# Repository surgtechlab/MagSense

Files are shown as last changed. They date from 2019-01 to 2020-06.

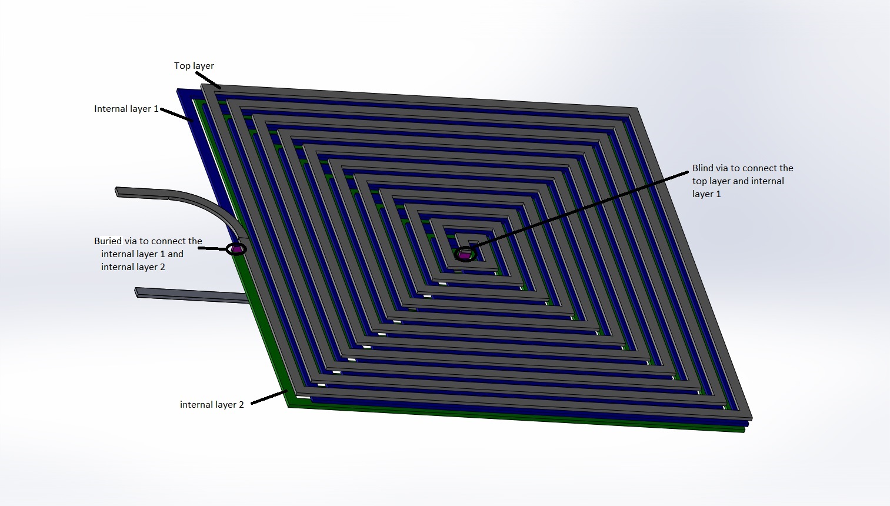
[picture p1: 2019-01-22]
02_Design/unityBoards/fromLefan/One_FS coil_Front view.JPG

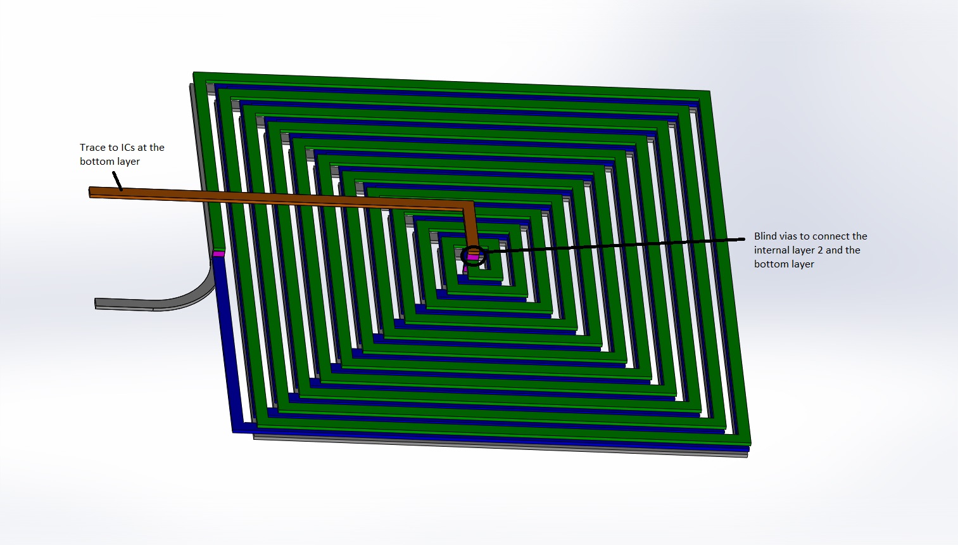
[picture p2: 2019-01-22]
02_Design/unityBoards/fromLefan/One_FScoil_Back view.JPG

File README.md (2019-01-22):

# MagSense

Code and Library for the Leeds Surgical Technologies Lab - Magnetic Sensing Platform

Maintained by Pete Culmer

Contributions from:
******************************
Chris Adams
Max Houghton
Pete Culmer
Belquis Haider

Links:
******************************
This owes a debt to the more general purpose MLX90393 driver
https://github.com/tedyapo/arduino-MLX90393

TODO LIST
******************************
Add Bluetooth communication
 
Simplify I2C code
  ***Use wrapper function to provide a single interface to the mutliple I2C buses - for the commands below:
  Wire.beginTransmission(_I2CAddress);
  Wire.write(0x80)
  Wire.endTransmission()
  Wire.requestFrom(_I2CAddress, 1);
  Wire.available()
  Wire.read();

Add handshaking and commands to I2C comms
  Start/stop/reset/ack packet etc.
  
Improve error checking of chip configuration (check registers after config)

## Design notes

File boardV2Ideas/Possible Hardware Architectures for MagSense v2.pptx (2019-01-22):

## Possible Hardware Architectures for MagSense v2

## Device

- Two interface protocols
  - i2c transfer up to 400 kHz
    - Not achieving this currently, possible clock stretching?
  - SPI transfer up to 10 MHz
  - Protocols very similar but SPI untested
- Running in burst mode
  - Should return last measurement obtained when read
  - Has interrupt pin to indicate measurement ready

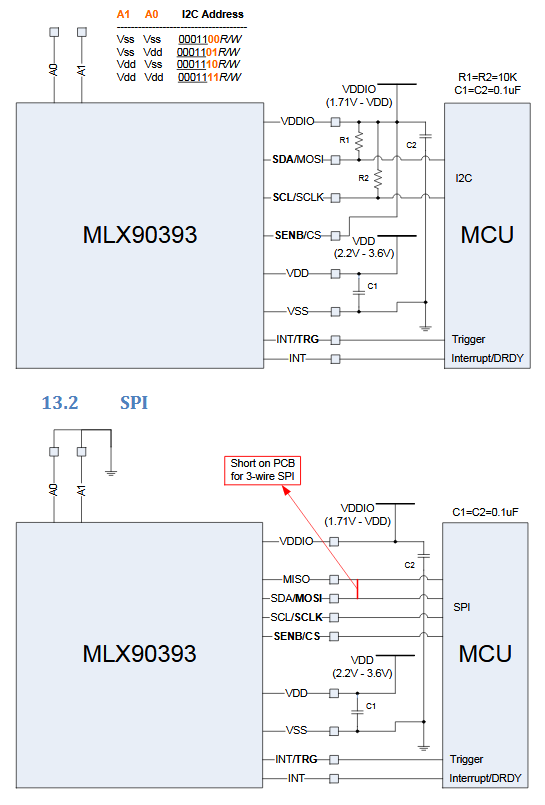
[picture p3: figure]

## Requirements

- ~100 nodes @ ~100 Hz
- Frontend easy to modify for changing TX protocol and SD card writing
- Simple PCB design for flex implementation
- Commonality between this design and hall effect version desirable

## Current architecture

- Each mux provides 4 i2c lines
- 4 nodes per mux line
- Common mux-select that connects 4 nodes to each teensy i2c bus at a time
- Asynchronous reading across each teensy bus gives 127 Hz
- Easy pickup in future, quick development
- Not scalable with same frame rate
- Messy, hard board design for 100+ nodes

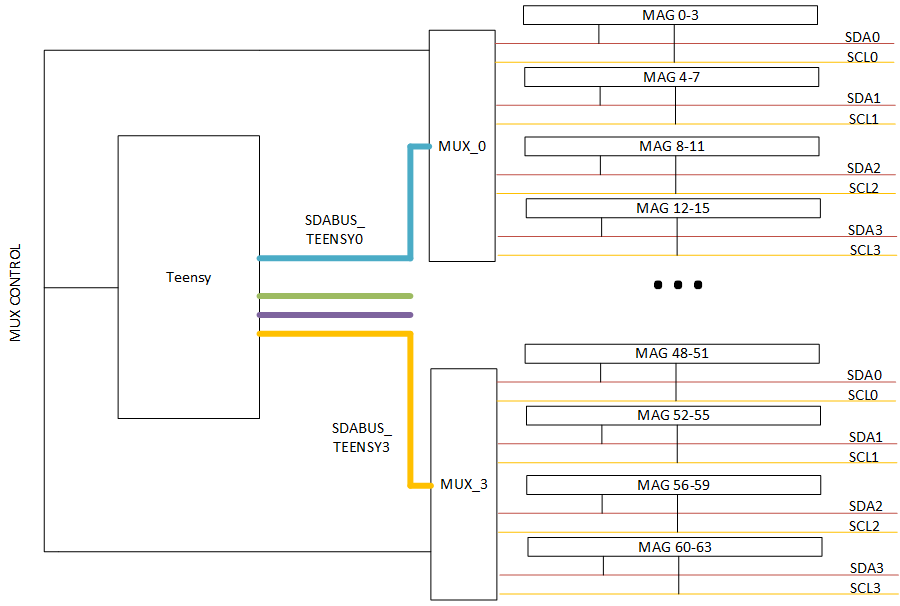
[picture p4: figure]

## ‘Smart mux’ architecture

- KL02 is tiny (2mm*2mm) AVR-based micro
- Each provides two local buses – 8 nodes
- Handles all data collection and then passes to teensy with SPI/i2c
- Run identical code, works position out from ADC value.
- High IC Count
- Large fan out from very small device
- Simple, quick design

## SPI version

- Same but with SPI instead
- Very high fanout
- Less ICs

## Passive FPGA Option

- Use FPGA to expand number of I/O busses available to uC
- Teensy programmer has no awareness of FPGA
- Long time to develop robust protocol that includes everything
- Provides most control to software
- As many i2c busses as FPGA pins
- Code reusable

## FPGA with SDRAM Interface

- Parallel interface between teensy and FPGA (fast)
- FPGA handles all low level comms and makes memory available on output
- Reading in AVR (including Arduino) simple as reading from array. Silicon handles everything.
- Simple FPGA design
- Simple software design
- No control over low level comms without changing FPGA design

## System on Chip

- Run ARM uC on FPGA
- Add busses as required
- ARM uC sees busses transparently
- Everything coded in C
- Might need lots of support electronics
- Expensive, licensing etc

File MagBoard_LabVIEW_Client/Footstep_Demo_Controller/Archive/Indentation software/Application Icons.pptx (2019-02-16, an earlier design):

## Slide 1

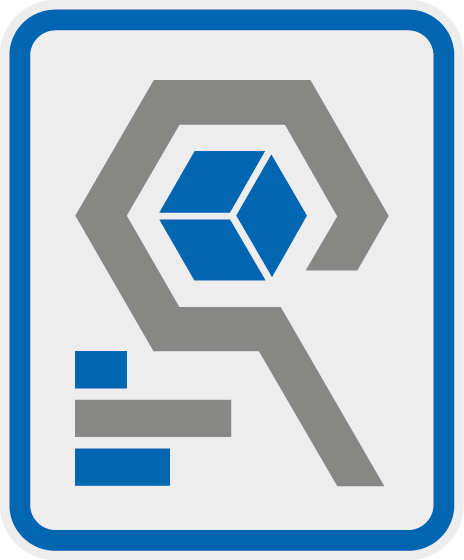
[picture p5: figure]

POLLUX

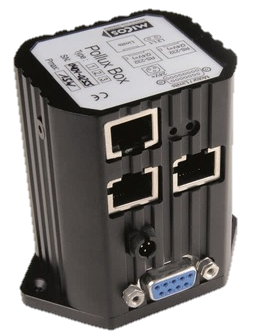
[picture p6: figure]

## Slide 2

SKIN

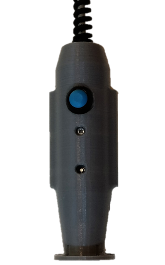
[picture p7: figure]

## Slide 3

TE77

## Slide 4

12

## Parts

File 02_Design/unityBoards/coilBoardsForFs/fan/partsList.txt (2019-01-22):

Ref Designator	QTY	Part Name	Value	Part Number
C1	1	C-EUC0402	10uF	C1	C0402
R1	1	R-EU_R0402	10k	R1	R0402
R2	1	R-EU_R0402	10k	R2	R0402
R3	1	R-EU_R0201	NOFIT	R3	R0201
R4	1	R-EU_R0201	NOFIT	R4	R0201
U1	1	LDC1614	LDC1614	U1	WQFN-16

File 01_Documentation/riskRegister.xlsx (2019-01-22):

ID | Description | Category | Probability | Impact | Mitigation | Response | Additional Time
1 | LDC acquisition too slow | Architechture | 0.5 | Late delivery due to architechture redesign | Test LDC response time | Change architechture | 100 hours
2
3
4
5
6
7
8
9
10
11
12
13
14
15
16

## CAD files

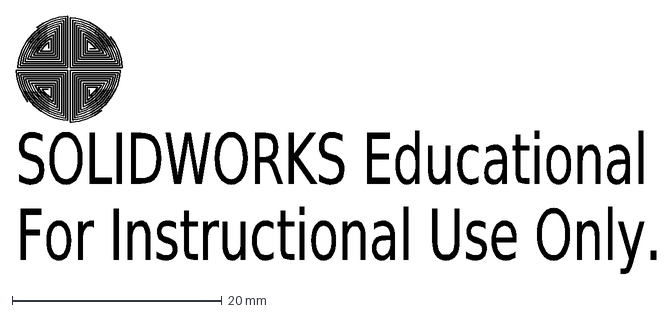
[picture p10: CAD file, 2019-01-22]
02_Design/unityBoards/fromLefan/fatCoils/fan/Internal Layer 1_FF.DXF
SOLIDWORKS Educational Product.
For Instructional Use Only.

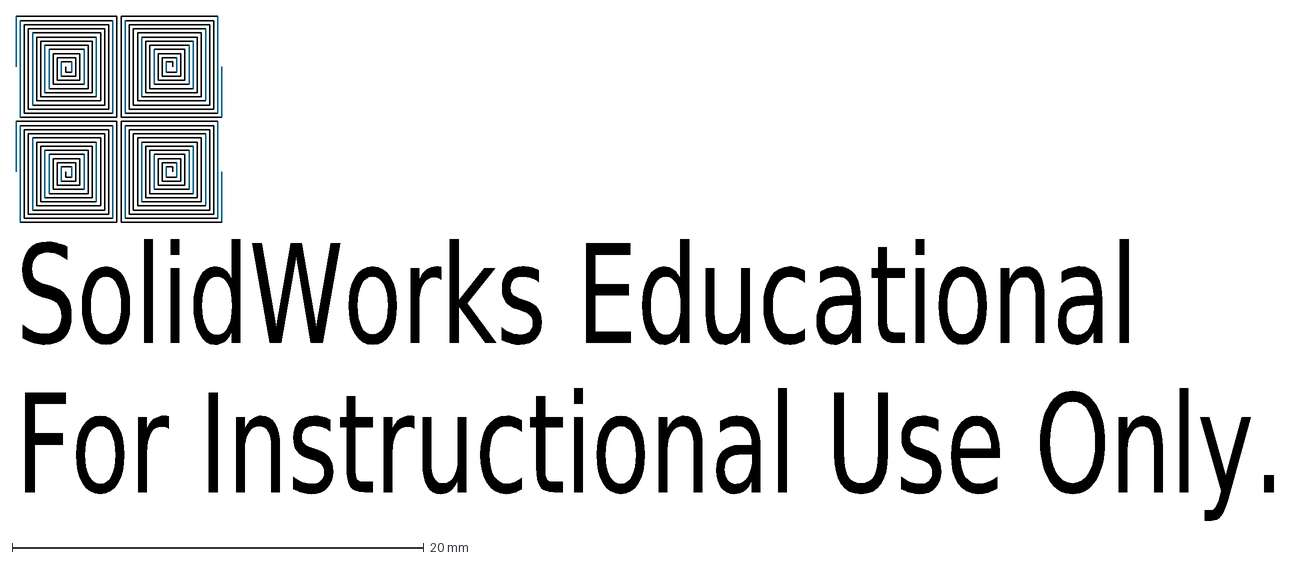
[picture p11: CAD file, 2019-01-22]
02_Design/unityBoards/fromLefan/fatCoils/square/Internal Layer 1_FS.DXF
SolidWorks Educational Edition.
For Instructional Use Only.

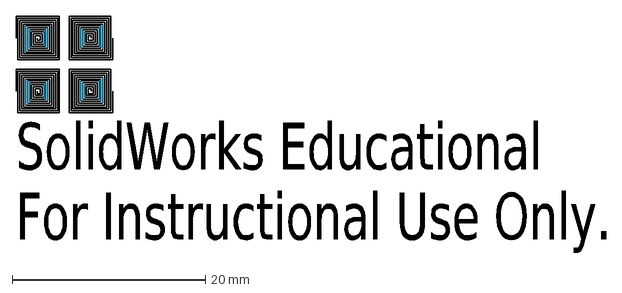
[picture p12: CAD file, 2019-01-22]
02_Design/unityBoards/fromLefan/Internal Layer 1.DXF
SolidWorks Educational Edition.
For Instructional Use Only.

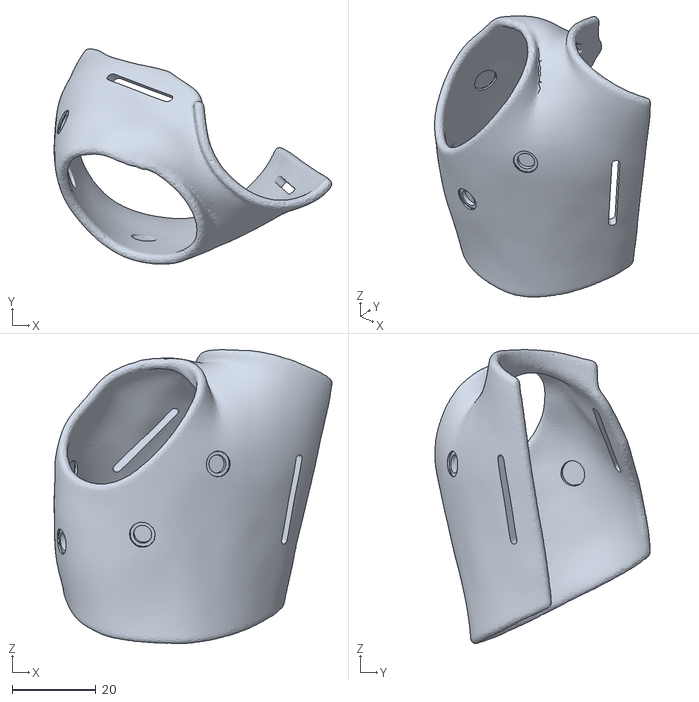
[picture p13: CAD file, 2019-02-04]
HAILO_Splint/HAILO_LabVIEW_Client/subvis/HAILO_Splint_lores.stl
66.5 x 51.6 x 70.4

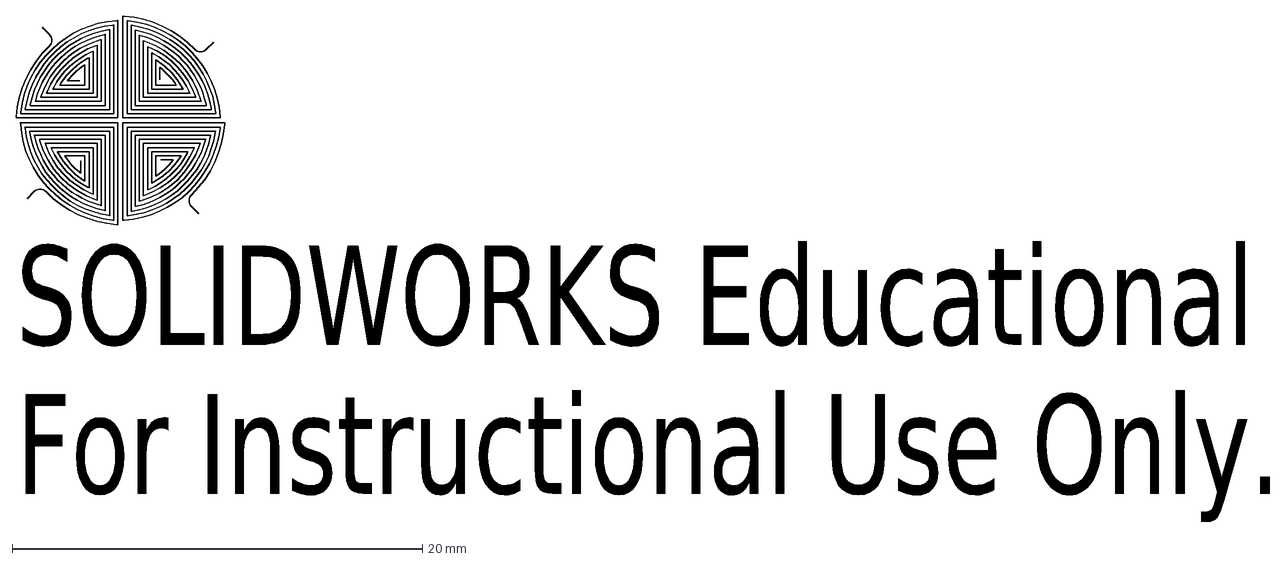
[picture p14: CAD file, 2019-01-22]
02_Design/unityBoards/fromLefan/fatCoils/fan/Top Layer_FF.DXF
SOLIDWORKS Educational Product.
For Instructional Use Only.

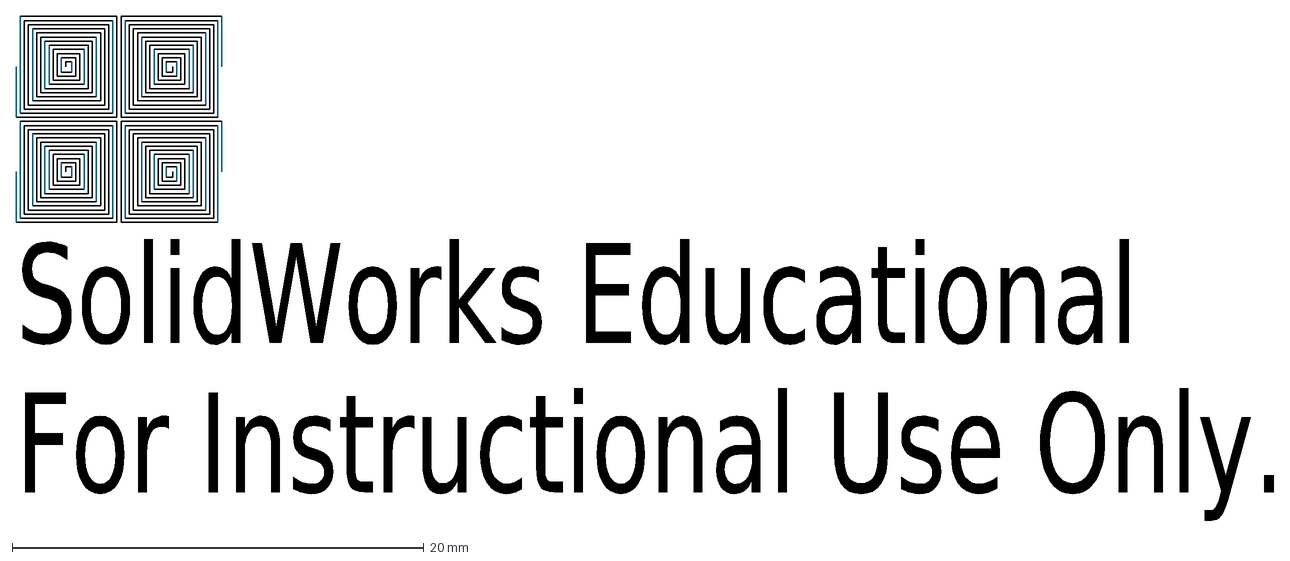
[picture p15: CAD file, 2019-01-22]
02_Design/unityBoards/fromLefan/fatCoils/square/Internal Layer 2_FS.DXF
SolidWorks Educational Edition.
For Instructional Use Only.

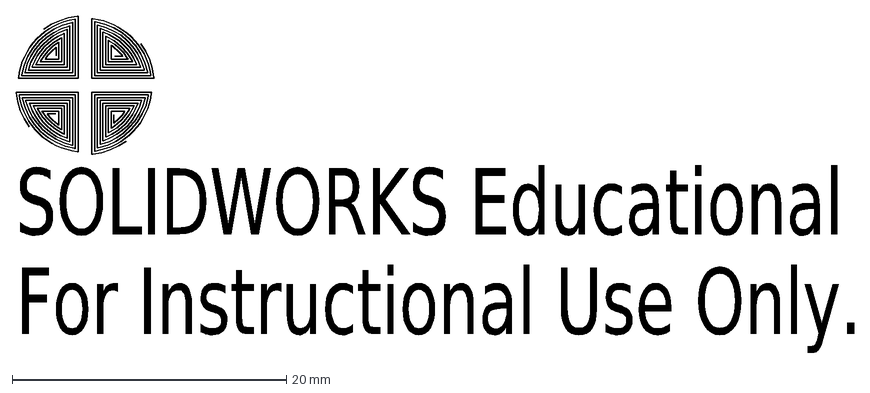
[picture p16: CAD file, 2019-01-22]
02_Design/unityBoards/fromLefan/Internal Layer 1_FF.DXF
SOLIDWORKS Educational Product.
For Instructional Use Only.

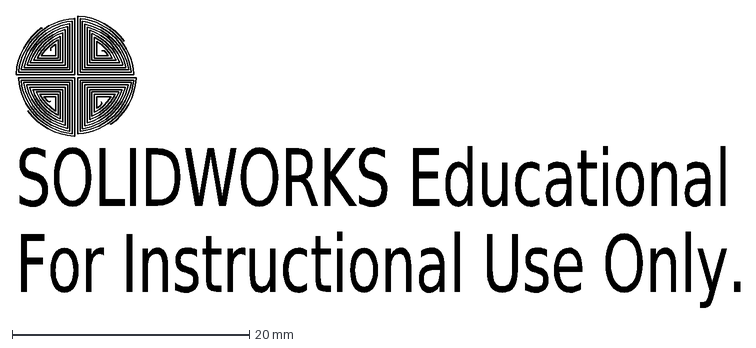
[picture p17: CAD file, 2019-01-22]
02_Design/unityBoards/fromLefan/fatCoils/fan/Internal Layer2_FF.DXF
SOLIDWORKS Educational Product.
For Instructional Use Only.

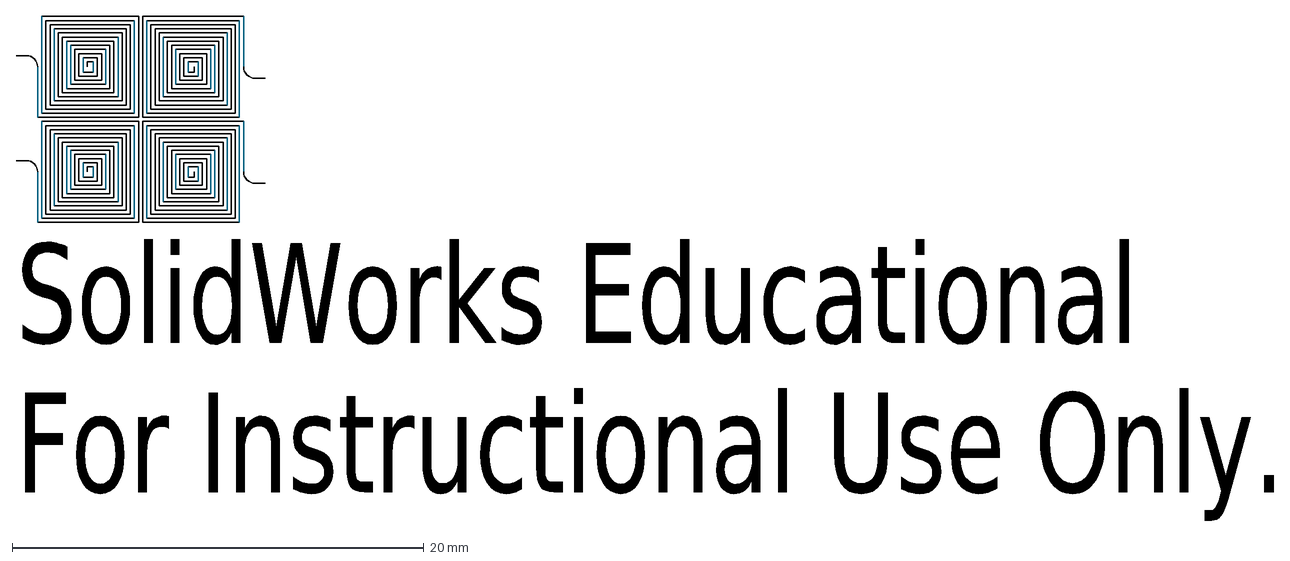
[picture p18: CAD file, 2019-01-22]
02_Design/unityBoards/fromLefan/fatCoils/square/Top Layer_FS.DXF
SolidWorks Educational Edition.
For Instructional Use Only.

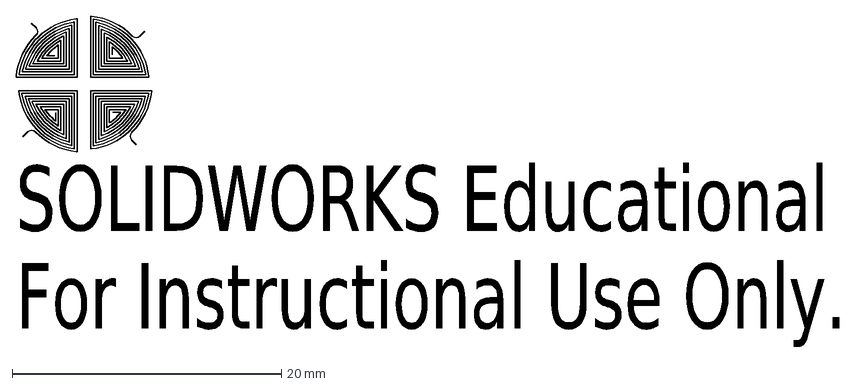
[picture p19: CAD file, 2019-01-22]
02_Design/unityBoards/fromLefan/Top Layer_FF.DXF
SOLIDWORKS Educational Product.
For Instructional Use Only.

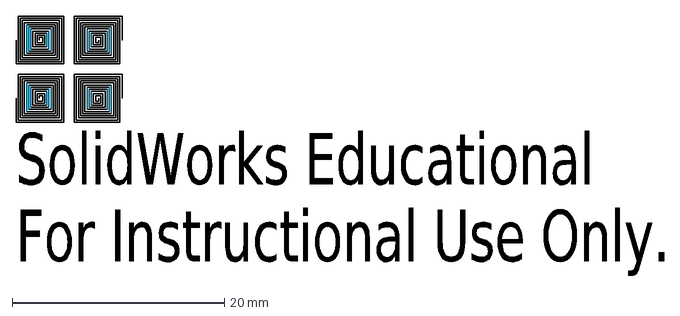
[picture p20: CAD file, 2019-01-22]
02_Design/unityBoards/fromLefan/Internal Layer 2.DXF
SolidWorks Educational Edition.
For Instructional Use Only.

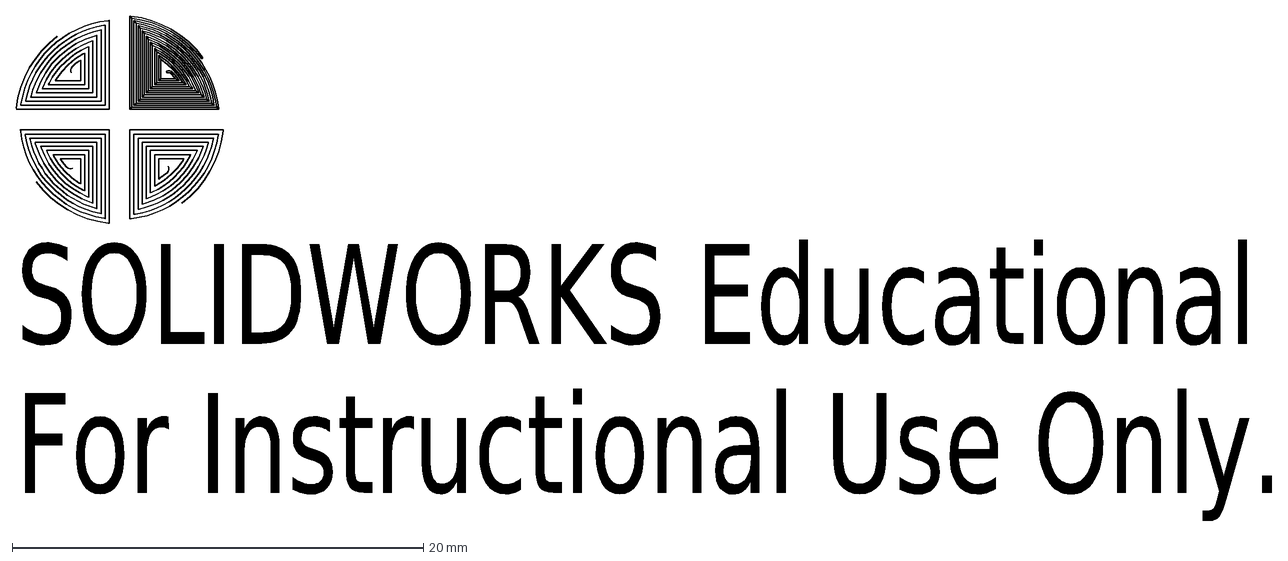
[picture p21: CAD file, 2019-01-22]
02_Design/unityBoards/fromLefan/Internal Layer2_FF.DXF
SOLIDWORKS Educational Product.
For Instructional Use Only.

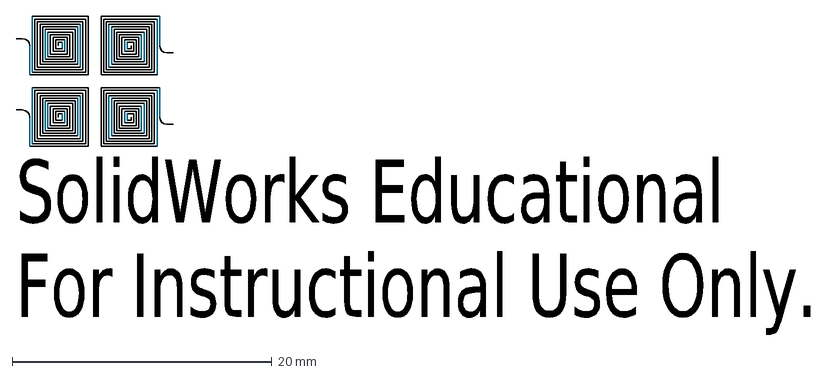
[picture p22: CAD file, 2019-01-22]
02_Design/unityBoards/fromLefan/Top layer.DXF
SolidWorks Educational Edition.
For Instructional Use Only.

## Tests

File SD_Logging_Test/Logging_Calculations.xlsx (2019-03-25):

Write size | 512
File Size (Mb) | 50
Mb in Bytes | 1000000
File Size (Bytes) | 50000000
Sample capacity (samples) | 97656.25
Sample capacity (seconds) | 976.5625

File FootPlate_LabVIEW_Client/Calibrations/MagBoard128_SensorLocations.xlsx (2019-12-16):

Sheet: Sensor Mappings
Reading Index | Exp Readings | Sensor No. | Mux | Address | I2C Line
0 | 0 | 0 | 0 | 0 | 0 | 0 | 1 | 2 | 3 | 4 | 5 | 6 | 7
4 | 4 | 1 | 0 | 1 | 0 | 8 | 9 | 10 | 11 | 12 | 13 | 14 | 15
8 | 8 | 2 | 0 | 2 | 0 | 16 | 17 | 18 | 19 | 20 | 21 | 22 | 23
12 | 12 | 3 | 0 | 3 | 0 | 24 | 25 | 26 | 27 | 28 | 29 | 30 | 31
1 | 64 | 4 | 0 | 0 | 1 | 32 | 33 | 34 | 35 | 36 | 37 | 38 | 39
5 | 68 | 5 | 0 | 1 | 1 | 40 | 41 | 42 | 43 | 44 | 45 | 46 | 47
9 | 72 | 6 | 0 | 2 | 1 | 48 | 49 | 50 | 51 | 52 | 53 | 54 | 55
13 | 76 | 7 | 0 | 3 | 1 | 56 | 57 | 58 | 59 | 60 | 61 | 62 | 63
16 | 16 | 8 | 0 | 4 | 0 | 64 | 65 | 66 | 67 | 68 | 69 | 70 | 71
20 | 20 | 9 | 0 | 5 | 0 | 72 | 73 | 74 | 75 | 76 | 77 | 78 | 79
24 | 24 | 10 | 0 | 6 | 0 | 80 | 81 | 82 | 83 | 84 | 85 | 86 | 87
28 | 28 | 11 | 0 | 7 | 0 | 88 | 89 | 90 | 91 | 92 | 93 | 94 | 95
17 | 80 | 12 | 0 | 4 | 1 | 96 | 97 | 98 | 99 | 100 | 101 | 102 | 103
21 | 84 | 13 | 0 | 5 | 1 | 104 | 105 | 106 | 107 | 108 | 109 | 110 | 111
25 | 88 | 14 | 0 | 6 | 1 | 112 | 113 | 114 | 115 | 116 | 117 | 118 | 119
29 | 92 | 15 | 0 | 7 | 1 | 120 | 121 | 122 | 123 | 124 | 125 | 126 | 127
15 | 108 | 16 | 0 | 3 | 3
11 | 104 | 17 | 0 | 2 | 3
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

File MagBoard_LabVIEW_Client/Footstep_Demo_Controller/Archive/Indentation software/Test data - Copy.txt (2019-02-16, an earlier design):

Time (s)	Position (mm)	Load (N)
0.000000	111.789776	1.361176
0.010000	111.786501	1.346186
0.020000	111.775299	1.331197
0.030000	111.751883	1.316207
0.040000	111.703909	1.301217
0.050000	111.638676	1.321845
0.060000	111.550345	1.367408
0.070000	111.456437	1.412971
0.080000	111.357319	1.458534
0.090000	111.255725	1.492918
0.100000	111.153961	1.475218
0.110000	111.056789	1.457518
0.120000	110.955606	1.439818
0.130000	110.853740	1.422118
0.140000	110.757337	1.392382
0.150000	110.657784	1.358441
0.160000	110.558312	1.324500
0.170000	110.457450	1.290559
0.180000	110.355619	1.284477
0.190000	110.254168	1.338613
0.200000	110.156777	1.392749
0.210000	110.057441	1.446885
0.220000	109.956434	1.501021
0.230000	109.855386	1.481179
0.240000	109.755832	1.456738
0.250000	109.658164	1.432297
0.260000	109.558811	1.407856
0.270000	109.456516	1.406176
0.280000	109.354657	1.424710
0.290000	109.255238	1.443244
0.300000	109.155117	1.461779
0.310000	109.055686	1.472111
0.320000	108.956086	1.421065
0.330000	108.856432	1.370019
0.340000	108.755793	1.318973
0.350000	108.653796	1.267927
0.360000	108.552033	1.264495
0.370000	108.450273	1.292039
0.380000	108.351837	1.319582
0.390000	108.252994	1.347126
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

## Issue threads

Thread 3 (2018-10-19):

Node 36 gets stuck at zero randomly. Fixes with power cycle.

matsalleh92, 2018-10-19:
A number of times now, node 36 gets stuck, appears to happen with stable and experimental code.
The behaviour is that is doesn't produce any output, just zeros.

Currently not sure if hardware of software problem.

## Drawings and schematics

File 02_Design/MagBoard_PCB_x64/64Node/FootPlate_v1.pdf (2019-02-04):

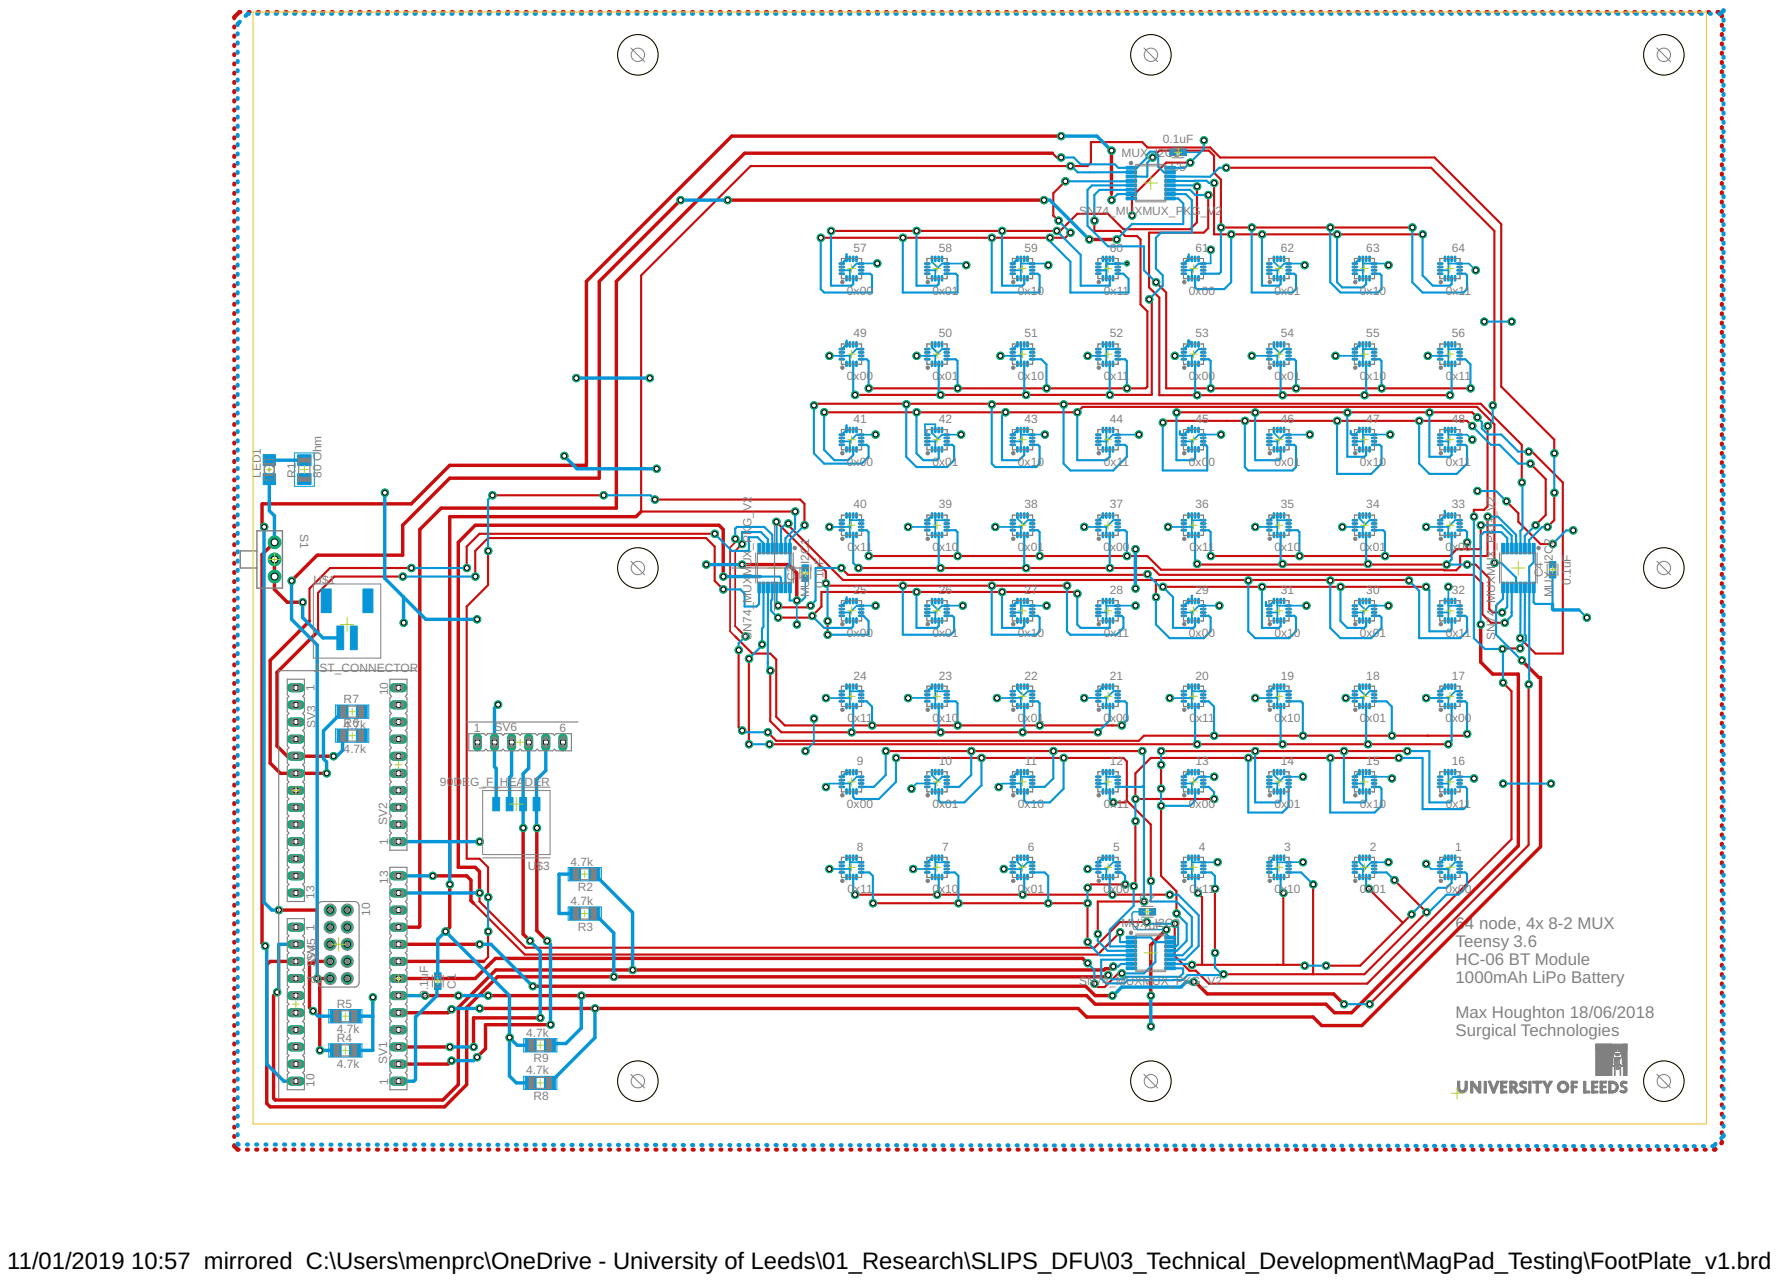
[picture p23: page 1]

11/01/2019 10:57 mirrored C:\Users\menprc\OneDrive - University of Leeds\01_Research\SLIPS_DFU\03_Technical_Development\MagPad_Testing\FootPlate_v1.brd

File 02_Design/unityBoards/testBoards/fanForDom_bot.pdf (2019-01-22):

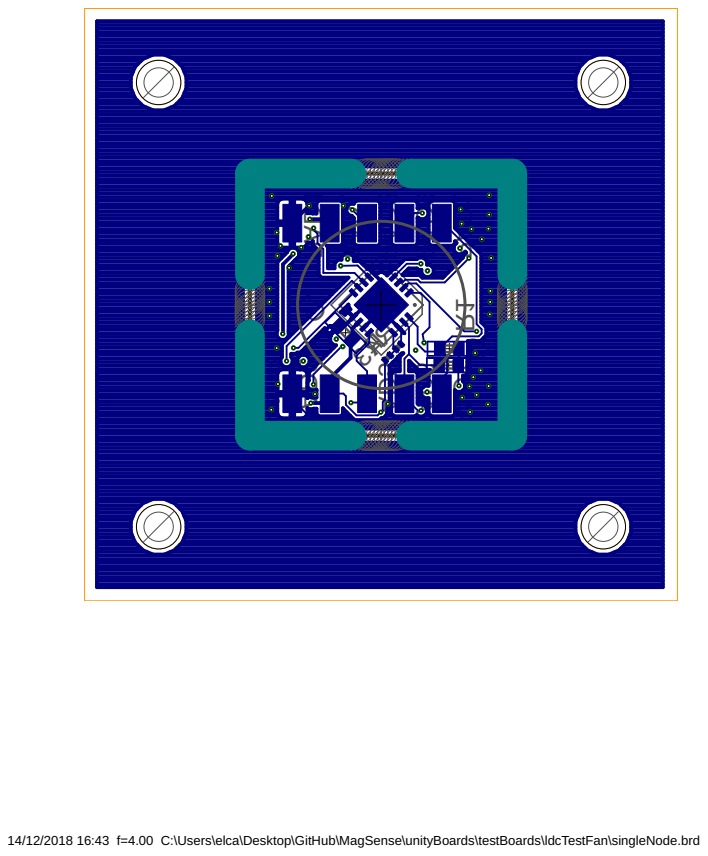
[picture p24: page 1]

14/12/2018 16:43 f=4.00 C:\Users\elca\Desktop\GitHub\MagSense\unityBoards\testBoards\ldcTestFan\singleNode.brd

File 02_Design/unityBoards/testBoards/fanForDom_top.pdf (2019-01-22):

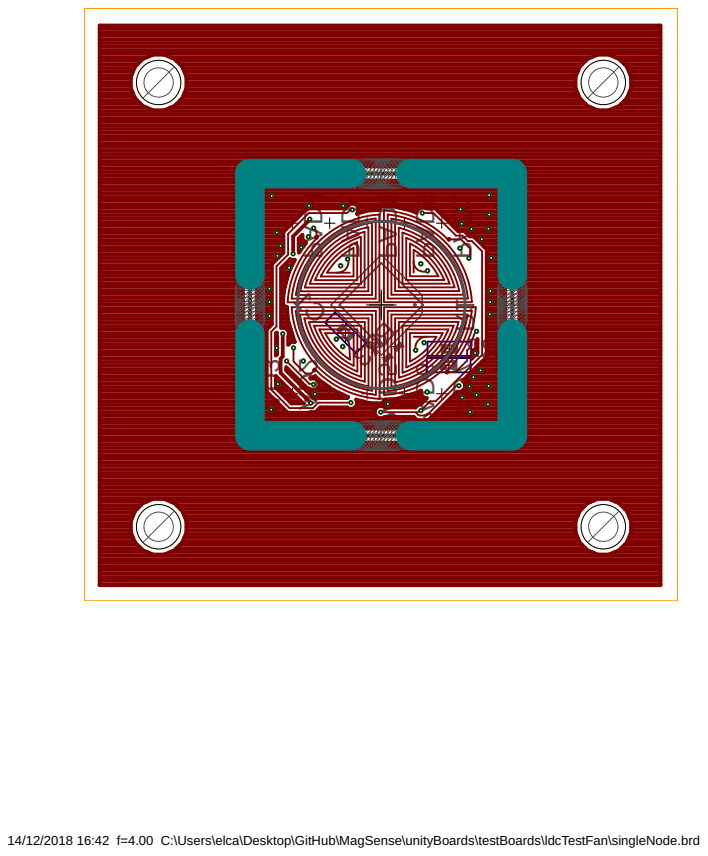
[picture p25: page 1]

14/12/2018 16:42 f=4.00 C:\Users\elca\Desktop\GitHub\MagSense\unityBoards\testBoards\ldcTestFan\singleNode.brd

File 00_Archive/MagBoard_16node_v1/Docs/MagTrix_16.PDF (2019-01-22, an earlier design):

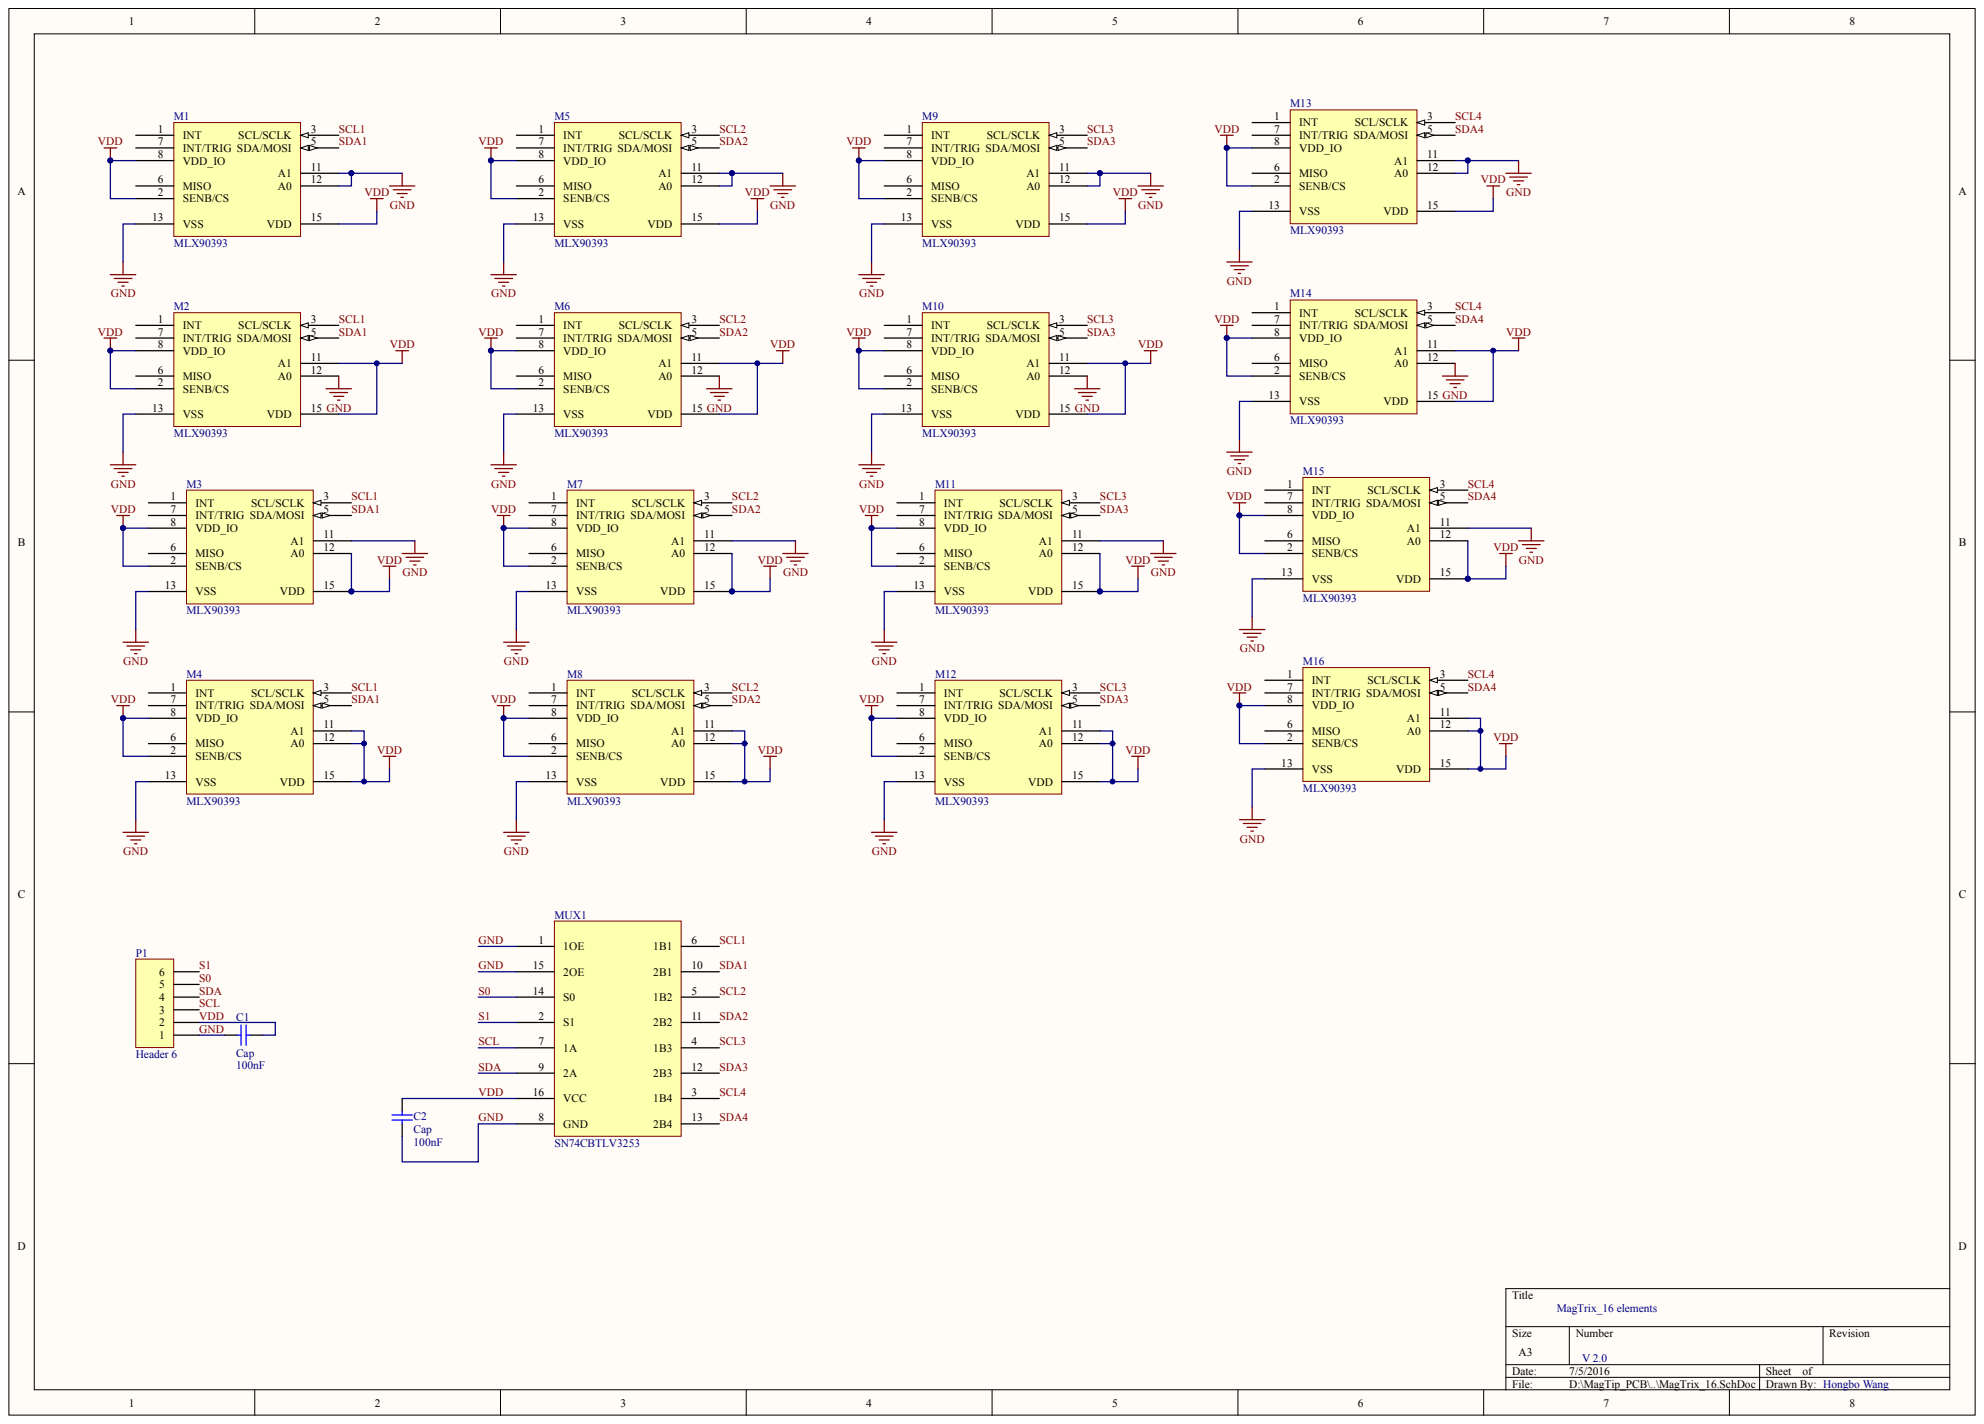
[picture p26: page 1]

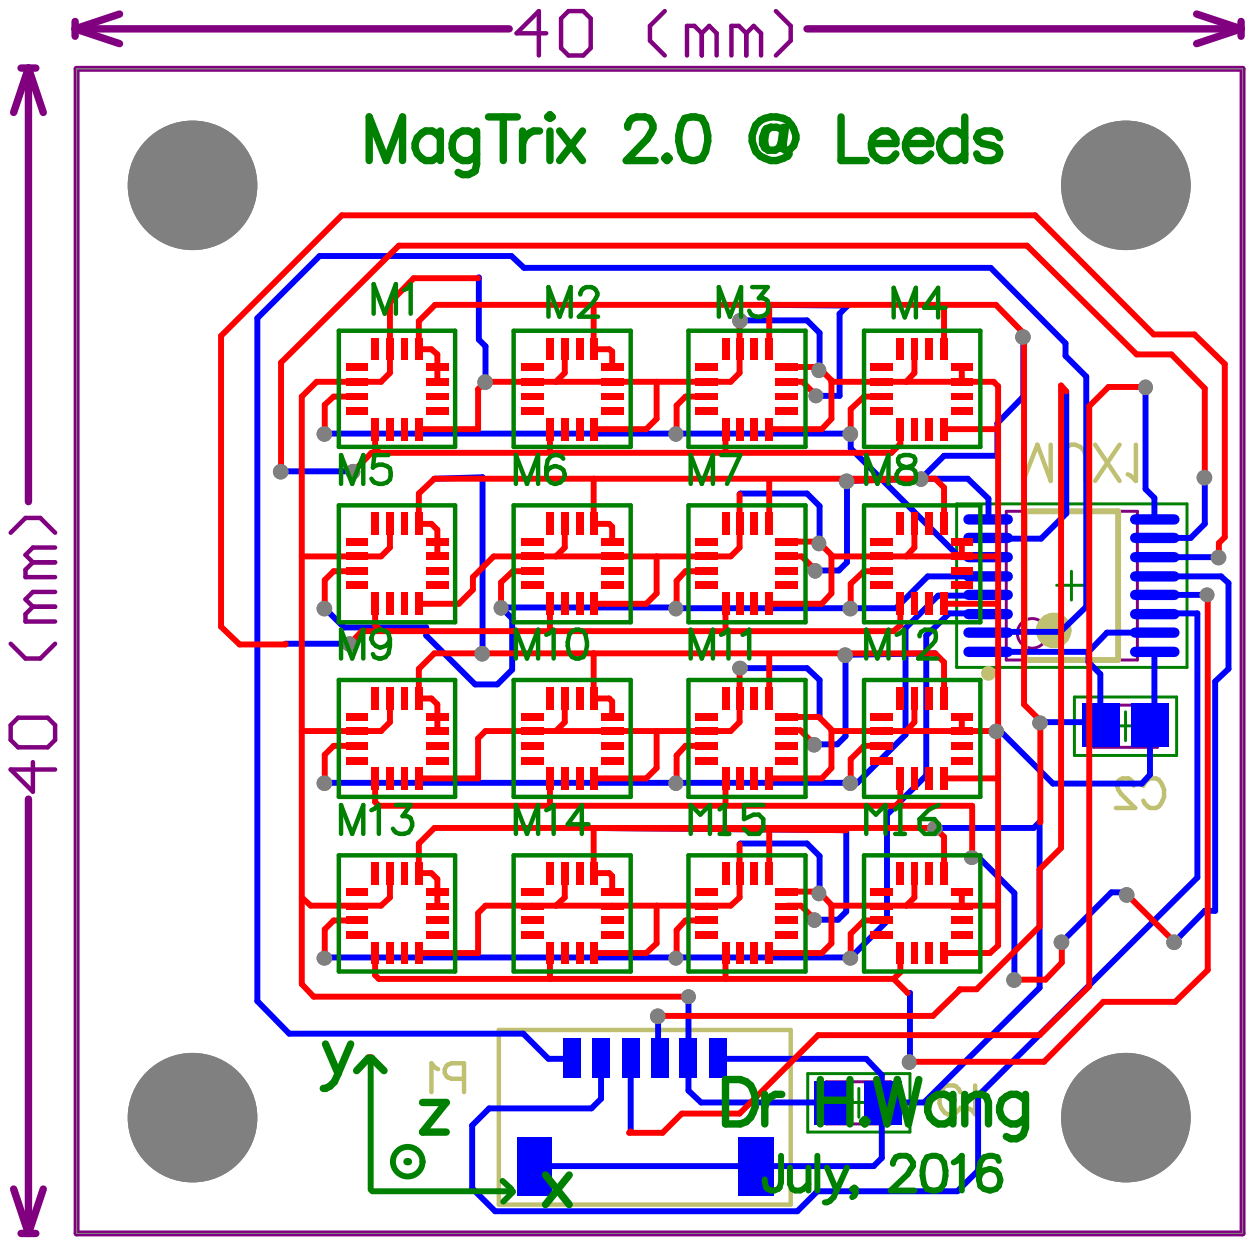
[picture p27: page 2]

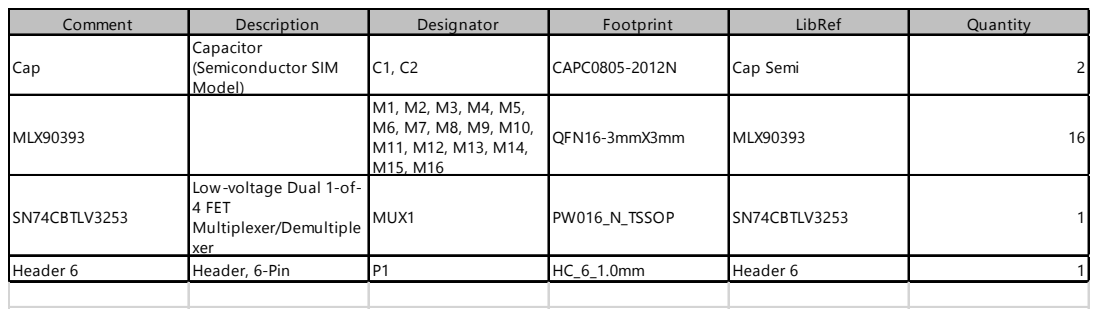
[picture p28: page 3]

Comment | Description | Designator | Footprint | LibRef | Quantity

Cap | Capacitor (Semiconductor SIM Model) | C1, C2 | CAPC0805-2012N | Cap Semi | 2

MLX90393 | | M1, M2, M3, M4, M5, M6, M7, M8, M9, M10, M11, M12, M13, M14, M15, M16 | QFN16-3mmX3mm | MLX90393 | 16

SN74CBTLV3253 | Low-voltage Dual 1-of-4 FET Multiplexer/Demultiple xer | MUX1 | PW016_N_TSSOP | SN74CBTLV3253 | 1

Header 6 | Header, 6-Pin | P1 | HC_6_1.0mm | Header 6 | 1

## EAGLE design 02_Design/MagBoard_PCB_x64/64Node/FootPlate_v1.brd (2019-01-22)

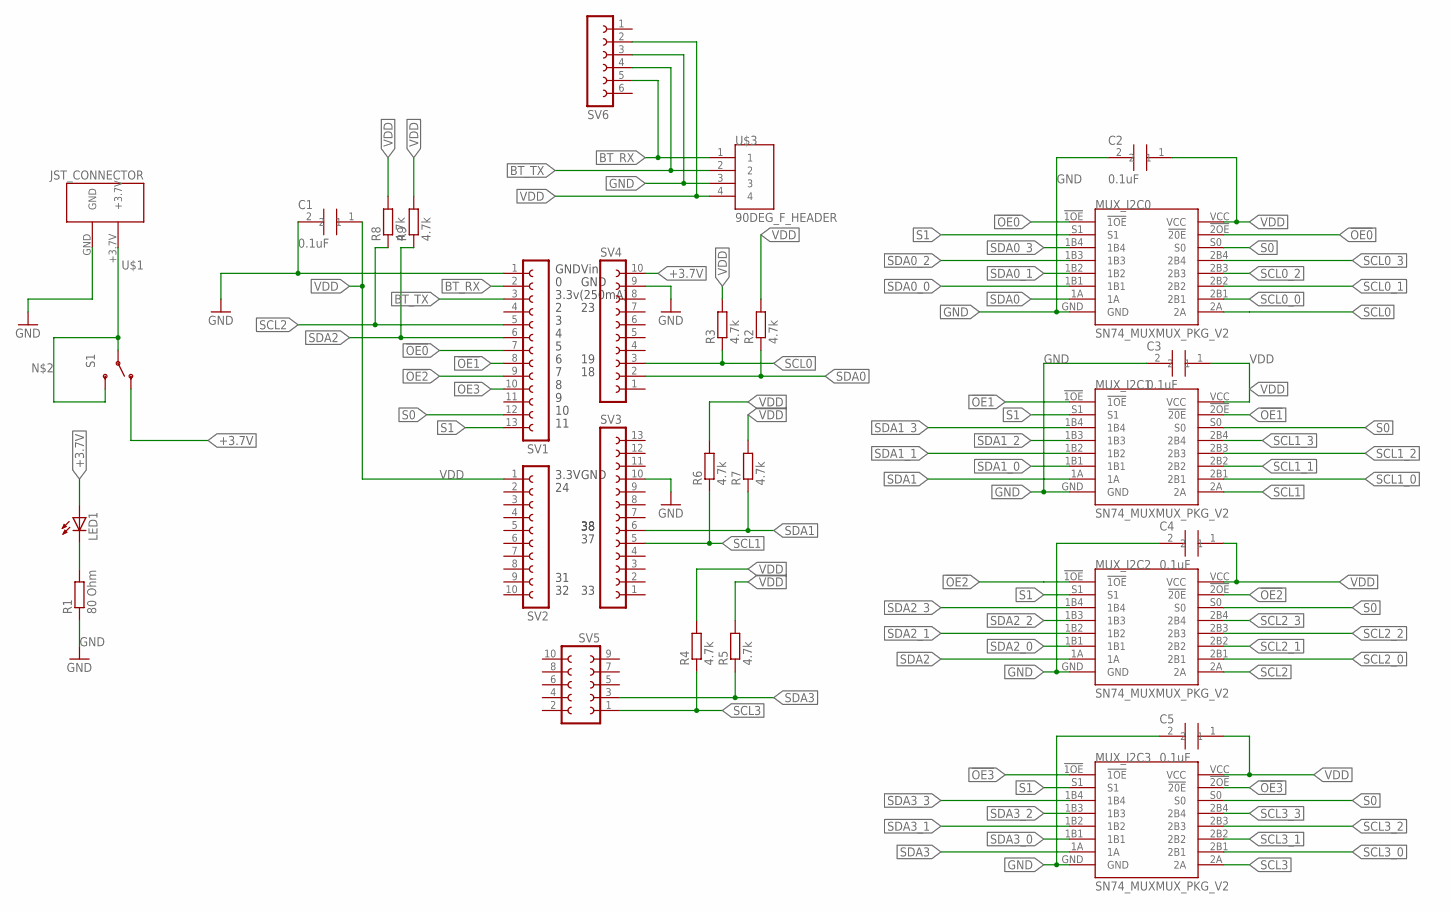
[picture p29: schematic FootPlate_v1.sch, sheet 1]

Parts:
C1, C2, C3, C4, C5: 0.1uF; CAPC1608X75
LED1: LEDSMT1206; 1206
MUX_I2C0, MUX_I2C1, MUX_I2C2, MUX_I2C3: SN74_MUXMUX_PKG_V2; SOP65P640X120-16
R1: 80 Ohm; M1206
R2, R3, R4, R5, R6, R7, R8, R9: 4.7k; R1206
S1: SWITCH_SPDT; SWITCH
SV1, SV3: FE13-1; FE13
SV2, SV4: FE10-1; FE10
SV5: FE05-2
SV6: FE06-1; FE06
U$1: JST_CONNECTOR; JST_PKG
U$3: 90DEG_F_HEADER; 90DEG_F_HEADER_PKG

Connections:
!OE0: MUX_I2C0.!1OE, MUX_I2C0.!2OE (!20E), SV1.7
!OE1: MUX_I2C1.!1OE, MUX_I2C1.!2OE (!20E), SV1.8
!OE2: MUX_I2C2.!1OE, MUX_I2C2.!2OE (!20E), SV1.9
!OE3: MUX_I2C3.!1OE, MUX_I2C3.!2OE (!20E), SV1.10
+3.7V: LED1.A, S1.1 (O), SV4.10
BT_RX: SV1.2, SV6.5, U$3.1
BT_TX: SV1.3, SV6.4, U$3.2
GND: C1.2 (1), C2.2 (1), C3.2 (1), C4.2 (1), C5.2 (1), MUX_I2C0.GND, MUX_I2C1.GND, MUX_I2C2.GND, MUX_I2C3.GND, R1.1, SV1.1, SV3.10, SV4.9, SV6.3, U$1.GND, U$3.3; also elsewhere on the board
unnamed: LED1.C, R1.2
unnamed: S1.2, S1.3 (S), U$1.+3.7V
S0: MUX_I2C0.S0, MUX_I2C1.S0, MUX_I2C2.S0, MUX_I2C3.S0, SV1.12
S1: MUX_I2C0.S1, MUX_I2C1.S1, MUX_I2C2.S1, MUX_I2C3.S1, SV1.13
SCL0: MUX_I2C0.2A, R3.1, SV4.3
SCL0_0: MUX_I2C0.2B1; also elsewhere on the board
SCL0_1: MUX_I2C0.2B2; also elsewhere on the board
SCL0_2: MUX_I2C0.2B3; also elsewhere on the board
SCL0_3: MUX_I2C0.2B4; also elsewhere on the board
SCL1: MUX_I2C1.2A, R6.1, SV3.5
SCL1_0: MUX_I2C1.2B1; also elsewhere on the board
SCL1_1: MUX_I2C1.2B2; also elsewhere on the board
SCL1_2: MUX_I2C1.2B3; also elsewhere on the board
SCL1_3: MUX_I2C1.2B4; also elsewhere on the board
SCL2: MUX_I2C2.2A, R8.1, SV1.5
SCL2_0: MUX_I2C2.2B1; also elsewhere on the board
SCL2_1: MUX_I2C2.2B2; also elsewhere on the board
SCL2_2: MUX_I2C2.2B3; also elsewhere on the board
SCL2_3: MUX_I2C2.2B4; also elsewhere on the board
SCL3: MUX_I2C3.2A, R4.1, SV5.1
SCL3_0: MUX_I2C3.2B1; also elsewhere on the board
SCL3_1: MUX_I2C3.2B2; also elsewhere on the board
SCL3_2: MUX_I2C3.2B3; also elsewhere on the board
SCL3_3: MUX_I2C3.2B4; also elsewhere on the board
SDA0: MUX_I2C0.1A, R2.1, SV4.2
SDA0_0: MUX_I2C0.1B1; also elsewhere on the board
SDA0_1: MUX_I2C0.1B2; also elsewhere on the board
SDA0_2: MUX_I2C0.1B3; also elsewhere on the board
SDA0_3: MUX_I2C0.1B4; also elsewhere on the board
SDA1: MUX_I2C1.1A, R7.1, SV3.6
SDA1_0: MUX_I2C1.1B1; also elsewhere on the board
SDA1_1: MUX_I2C1.1B2; also elsewhere on the board
SDA1_2: MUX_I2C1.1B3; also elsewhere on the board
SDA1_3: MUX_I2C1.1B4; also elsewhere on the board
SDA2: MUX_I2C2.1A, R9.1, SV1.6
SDA2_0: MUX_I2C2.1B1; also elsewhere on the board
SDA2_1: MUX_I2C2.1B2; also elsewhere on the board
SDA2_2: MUX_I2C2.1B3; also elsewhere on the board
SDA2_3: MUX_I2C2.1B4; also elsewhere on the board
SDA3: MUX_I2C3.1A, R5.1, SV5.3
SDA3_0: MUX_I2C3.1B1; also elsewhere on the board
SDA3_1: MUX_I2C3.1B2; also elsewhere on the board
SDA3_2: MUX_I2C3.1B3; also elsewhere on the board
SDA3_3: MUX_I2C3.1B4; also elsewhere on the board
VDD: C1.1 (2), C2.1 (2), C3.1 (2), C4.1 (2), C5.1 (2), MUX_I2C0.VCC, MUX_I2C1.VCC, MUX_I2C2.VCC, MUX_I2C3.VCC, R2.2, R3.2, R4.2, R5.2, R6.2, R7.2, R8.2, R9.2, SV2.1, SV6.2, U$3.4; also elsewhere on the board

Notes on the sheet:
GND
3.3V
Vin
3.3v(250mA)

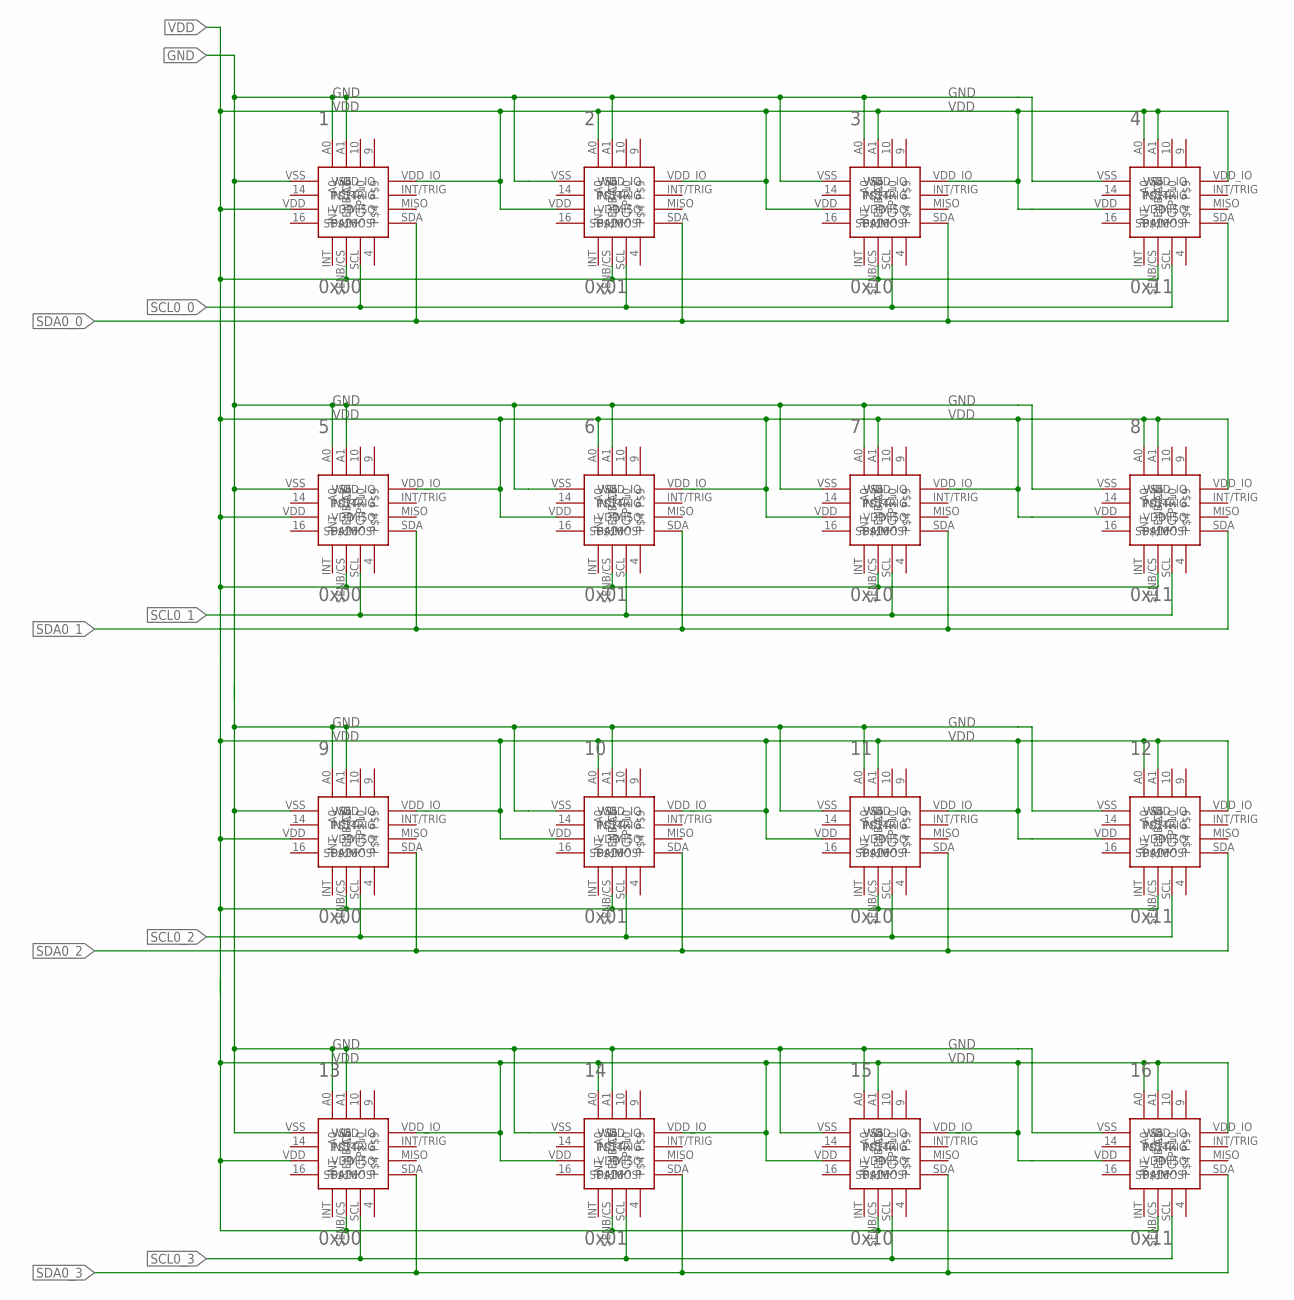
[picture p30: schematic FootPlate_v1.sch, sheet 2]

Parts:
1, 5, 9, 13: 0x00; MLX90393_PKG
2, 6, 10, 14: 0x01; MLX90393_PKG
3, 7, 11, 15: 0x10; MLX90393_PKG
4, 8, 12, 16: 0x11; MLX90393_PKG

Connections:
GND: 1.A0, 1.A1, 1.VSS, 2.A1, 2.VSS, 3.A0, 3.VSS, 4.VSS, 5.A0, 5.A1, 5.VSS, 6.A1, 6.VSS, 7.A0, 7.VSS, 8.VSS, 9.A0, 9.A1, 9.VSS, 10.A1, 10.VSS, 11.A0, 11.VSS, 12.VSS, 13.A0, 13.A1, 13.VSS, 14.A1, 14.VSS, 15.A0, 15.VSS, 16.VSS; also elsewhere on the board
SCL0_0: 1.SCL, 2.SCL, 3.SCL, 4.SCL; also elsewhere on the board
SCL0_1: 5.SCL, 6.SCL, 7.SCL, 8.SCL; also elsewhere on the board
SCL0_2: 9.SCL, 10.SCL, 11.SCL, 12.SCL; also elsewhere on the board
SCL0_3: 13.SCL, 14.SCL, 15.SCL, 16.SCL; also elsewhere on the board
SDA0_0: 1.SDA (SDA/MOSI), 2.SDA (SDA/MOSI), 3.SDA (SDA/MOSI), 4.SDA (SDA/MOSI); also elsewhere on the board
SDA0_1: 5.SDA (SDA/MOSI), 6.SDA (SDA/MOSI), 7.SDA (SDA/MOSI), 8.SDA (SDA/MOSI); also elsewhere on the board
SDA0_2: 9.SDA (SDA/MOSI), 10.SDA (SDA/MOSI), 11.SDA (SDA/MOSI), 12.SDA (SDA/MOSI); also elsewhere on the board
SDA0_3: 13.SDA (SDA/MOSI), 14.SDA (SDA/MOSI), 15.SDA (SDA/MOSI), 16.SDA (SDA/MOSI); also elsewhere on the board
VDD: 1.SENB/CS, 1.VDD, 1.VDD_IO, 2.A0, 2.SENB/CS, 2.VDD, 2.VDD_IO, 3.A1, 3.SENB/CS, 3.VDD, 3.VDD_IO, 4.A0, 4.A1, 4.SENB/CS, 4.VDD, 4.VDD_IO, 5.SENB/CS, 5.VDD, 5.VDD_IO, 6.A0, 6.SENB/CS, 6.VDD, 6.VDD_IO, 7.A1, 7.SENB/CS, 7.VDD, 7.VDD_IO, 8.A0, 8.A1, 8.SENB/CS, 8.VDD, 8.VDD_IO, 9.SENB/CS, 9.VDD, 9.VDD_IO, 10.A0, 10.SENB/CS, 10.VDD, 10.VDD_IO, 11.A1, 11.SENB/CS, 11.VDD, 11.VDD_IO, 12.A0, 12.A1, 12.SENB/CS, 12.VDD, 12.VDD_IO, 13.SENB/CS, 13.VDD, 13.VDD_IO, 14.A0, 14.SENB/CS, 14.VDD, 14.VDD_IO, 15.A1, 15.SENB/CS, 15.VDD, 15.VDD_IO, 16.A0, 16.A1, 16.SENB/CS, 16.VDD, 16.VDD_IO; also elsewhere on the board

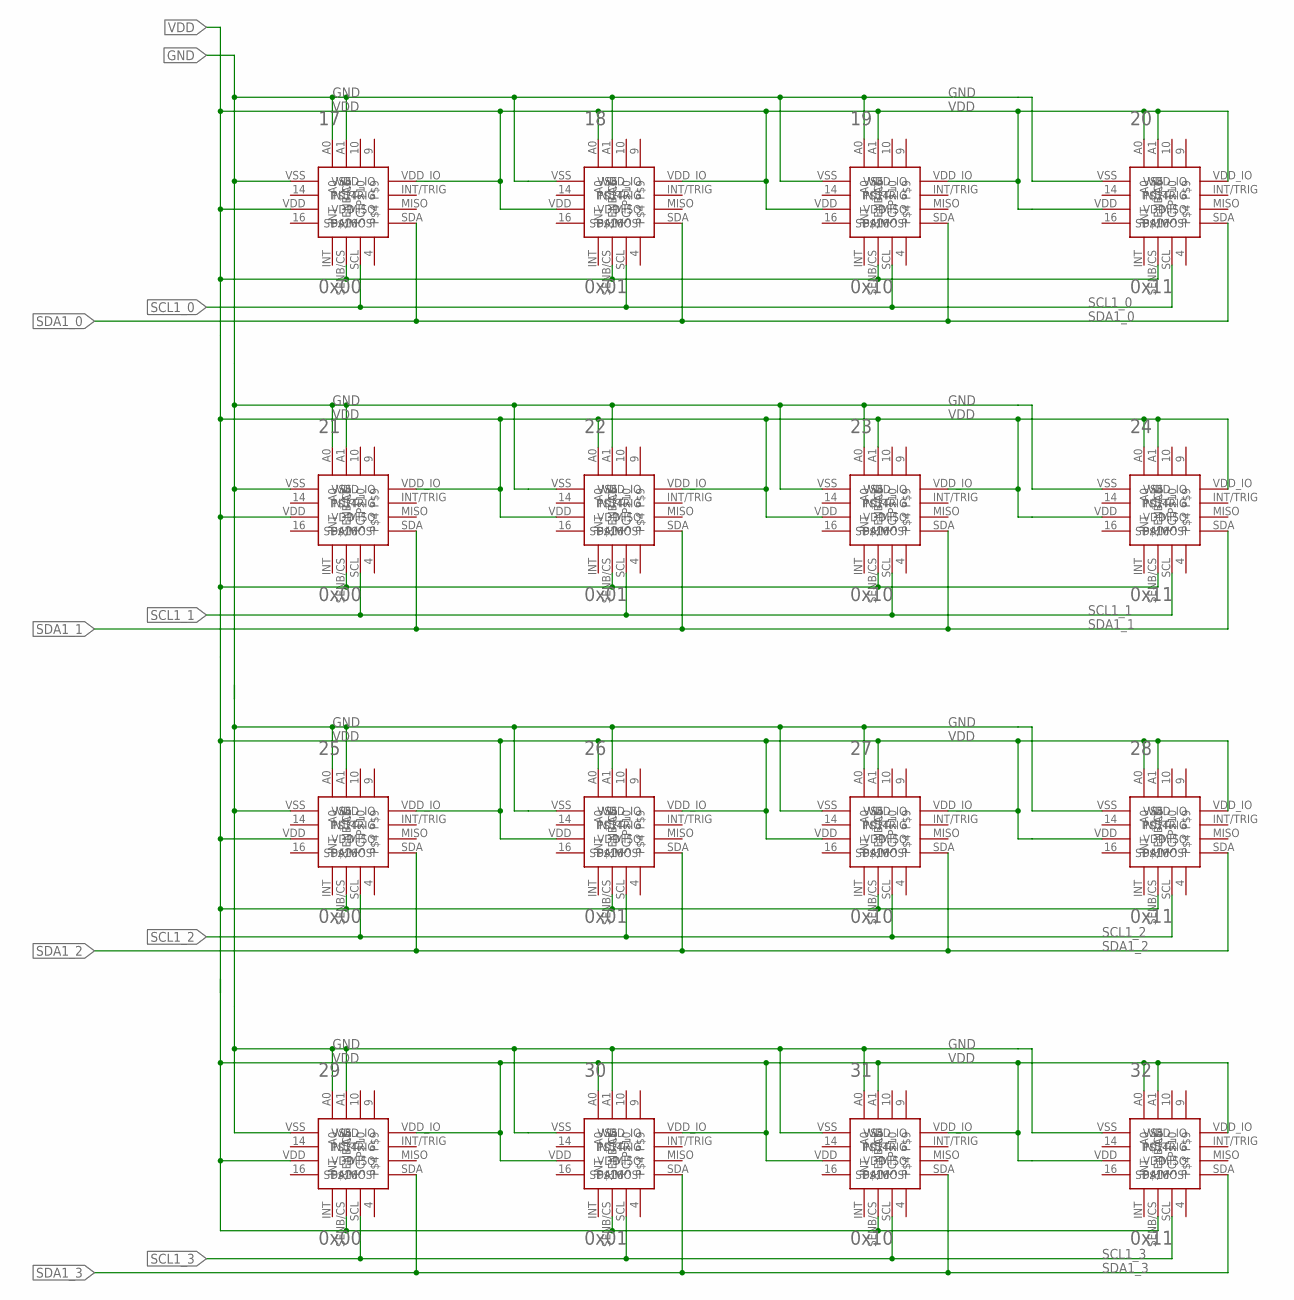
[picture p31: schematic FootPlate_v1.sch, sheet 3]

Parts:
17, 21, 25, 29: 0x00; MLX90393_PKG
18, 22, 26, 30: 0x01; MLX90393_PKG
19, 23, 27, 31: 0x10; MLX90393_PKG
20, 24, 28, 32: 0x11; MLX90393_PKG

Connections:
GND: 17.A0, 17.A1, 17.VSS, 18.A1, 18.VSS, 19.A0, 19.VSS, 20.VSS, 21.A0, 21.A1, 21.VSS, 22.A1, 22.VSS, 23.A0, 23.VSS, 24.VSS, 25.A0, 25.A1, 25.VSS, 26.A1, 26.VSS, 27.A0, 27.VSS, 28.VSS, 29.A0, 29.A1, 29.VSS, 30.A1, 30.VSS, 31.A0, 31.VSS, 32.VSS; also elsewhere on the board
SCL1_0: 17.SCL, 18.SCL, 19.SCL, 20.SCL; also elsewhere on the board
SCL1_1: 21.SCL, 22.SCL, 23.SCL, 24.SCL; also elsewhere on the board
SCL1_2: 25.SCL, 26.SCL, 27.SCL, 28.SCL; also elsewhere on the board
SCL1_3: 29.SCL, 30.SCL, 31.SCL, 32.SCL; also elsewhere on the board
SDA1_0: 17.SDA (SDA/MOSI), 18.SDA (SDA/MOSI), 19.SDA (SDA/MOSI), 20.SDA (SDA/MOSI); also elsewhere on the board
SDA1_1: 21.SDA (SDA/MOSI), 22.SDA (SDA/MOSI), 23.SDA (SDA/MOSI), 24.SDA (SDA/MOSI); also elsewhere on the board
SDA1_2: 25.SDA (SDA/MOSI), 26.SDA (SDA/MOSI), 27.SDA (SDA/MOSI), 28.SDA (SDA/MOSI); also elsewhere on the board
SDA1_3: 29.SDA (SDA/MOSI), 30.SDA (SDA/MOSI), 31.SDA (SDA/MOSI), 32.SDA (SDA/MOSI); also elsewhere on the board
VDD: 17.SENB/CS, 17.VDD, 17.VDD_IO, 18.A0, 18.SENB/CS, 18.VDD, 18.VDD_IO, 19.A1, 19.SENB/CS, 19.VDD, 19.VDD_IO, 20.A0, 20.A1, 20.SENB/CS, 20.VDD, 20.VDD_IO, 21.SENB/CS, 21.VDD, 21.VDD_IO, 22.A0, 22.SENB/CS, 22.VDD, 22.VDD_IO, 23.A1, 23.SENB/CS, 23.VDD, 23.VDD_IO, 24.A0, 24.A1, 24.SENB/CS, 24.VDD, 24.VDD_IO, 25.SENB/CS, 25.VDD, 25.VDD_IO, 26.A0, 26.SENB/CS, 26.VDD, 26.VDD_IO, 27.A1, 27.SENB/CS, 27.VDD, 27.VDD_IO, 28.A0, 28.A1, 28.SENB/CS, 28.VDD, 28.VDD_IO, 29.SENB/CS, 29.VDD, 29.VDD_IO, 30.A0, 30.SENB/CS, 30.VDD, 30.VDD_IO, 31.A1, 31.SENB/CS, 31.VDD, 31.VDD_IO, 32.A0, 32.A1, 32.SENB/CS, 32.VDD, 32.VDD_IO; also elsewhere on the board

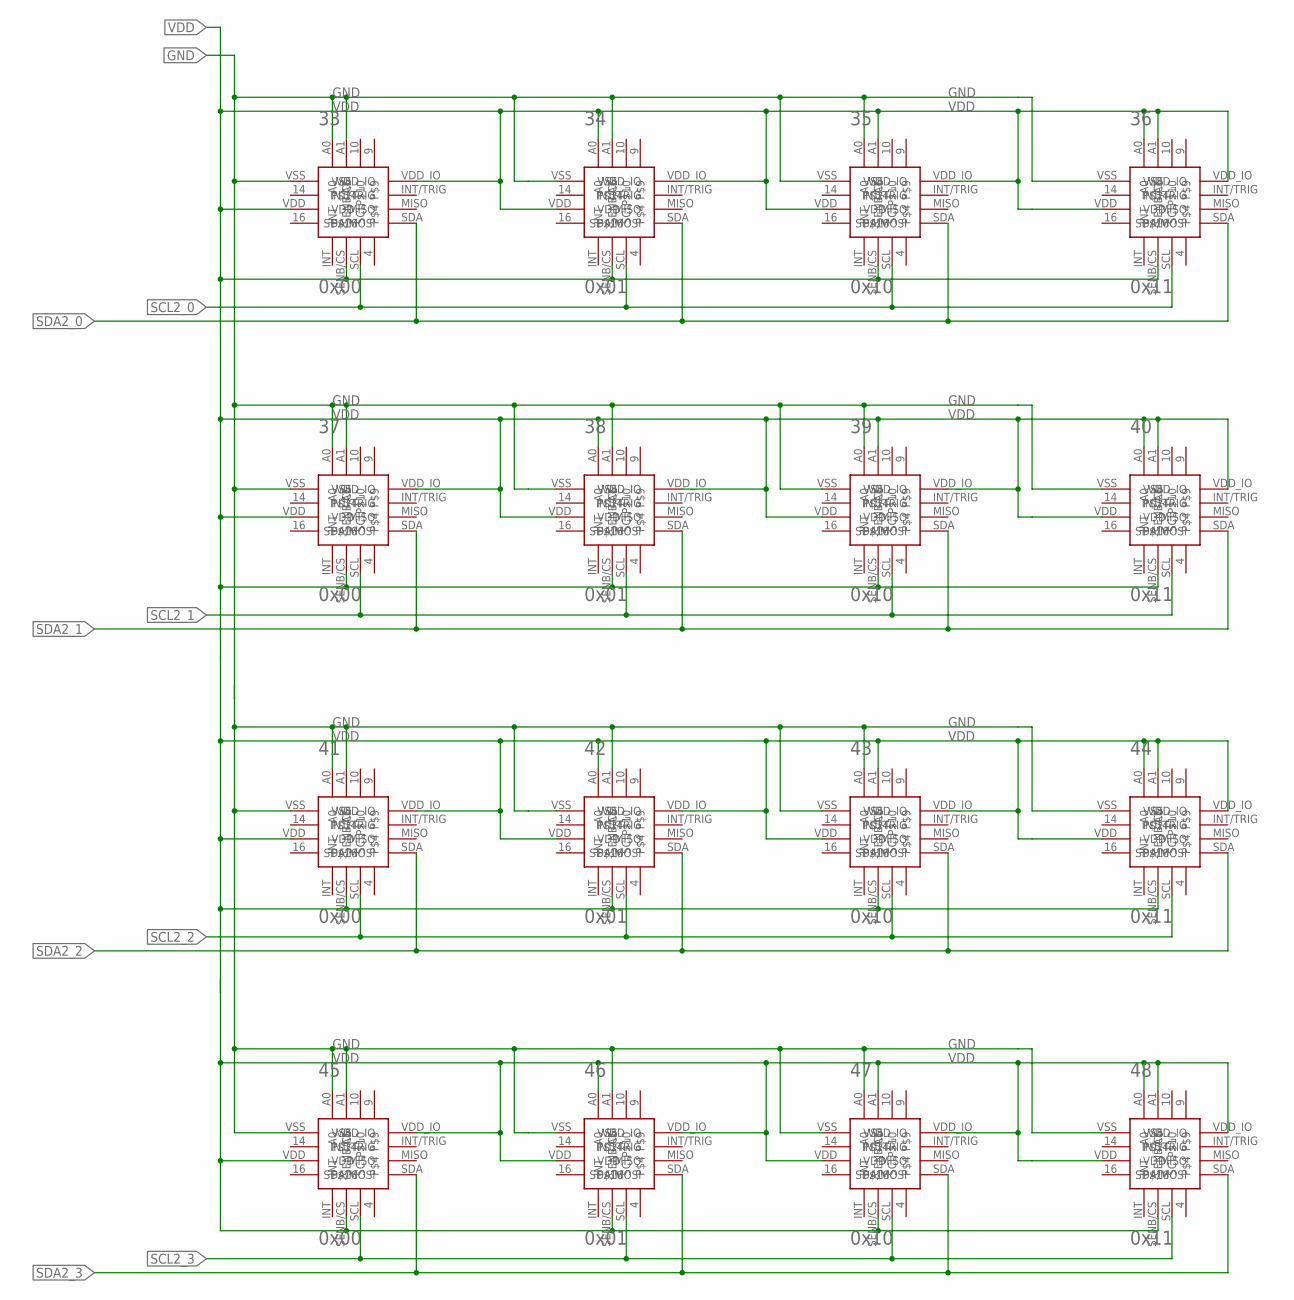
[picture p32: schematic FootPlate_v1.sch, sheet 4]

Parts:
33, 37, 41, 45: 0x00; MLX90393_PKG
34, 38, 42, 46: 0x01; MLX90393_PKG
35, 39, 43, 47: 0x10; MLX90393_PKG
36, 40, 44, 48: 0x11; MLX90393_PKG

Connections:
GND: 33.A0, 33.A1, 33.VSS, 34.A1, 34.VSS, 35.A0, 35.VSS, 36.VSS, 37.A0, 37.A1, 37.VSS, 38.A1, 38.VSS, 39.A0, 39.VSS, 40.VSS, 41.A0, 41.A1, 41.VSS, 42.A1, 42.VSS, 43.A0, 43.VSS, 44.VSS, 45.A0, 45.A1, 45.VSS, 46.A1, 46.VSS, 47.A0, 47.VSS, 48.VSS; also elsewhere on the board
SCL2_0: 33.SCL, 34.SCL, 35.SCL, 36.SCL; also elsewhere on the board
SCL2_1: 37.SCL, 38.SCL, 39.SCL, 40.SCL; also elsewhere on the board
SCL2_2: 41.SCL, 42.SCL, 43.SCL, 44.SCL; also elsewhere on the board
SCL2_3: 45.SCL, 46.SCL, 47.SCL, 48.SCL; also elsewhere on the board
SDA2_0: 33.SDA (SDA/MOSI), 34.SDA (SDA/MOSI), 35.SDA (SDA/MOSI), 36.SDA (SDA/MOSI); also elsewhere on the board
SDA2_1: 37.SDA (SDA/MOSI), 38.SDA (SDA/MOSI), 39.SDA (SDA/MOSI), 40.SDA (SDA/MOSI); also elsewhere on the board
SDA2_2: 41.SDA (SDA/MOSI), 42.SDA (SDA/MOSI), 43.SDA (SDA/MOSI), 44.SDA (SDA/MOSI); also elsewhere on the board
SDA2_3: 45.SDA (SDA/MOSI), 46.SDA (SDA/MOSI), 47.SDA (SDA/MOSI), 48.SDA (SDA/MOSI); also elsewhere on the board
VDD: 33.SENB/CS, 33.VDD, 33.VDD_IO, 34.A0, 34.SENB/CS, 34.VDD, 34.VDD_IO, 35.A1, 35.SENB/CS, 35.VDD, 35.VDD_IO, 36.A0, 36.A1, 36.SENB/CS, 36.VDD, 36.VDD_IO, 37.SENB/CS, 37.VDD, 37.VDD_IO, 38.A0, 38.SENB/CS, 38.VDD, 38.VDD_IO, 39.A1, 39.SENB/CS, 39.VDD, 39.VDD_IO, 40.A0, 40.A1, 40.SENB/CS, 40.VDD, 40.VDD_IO, 41.SENB/CS, 41.VDD, 41.VDD_IO, 42.A0, 42.SENB/CS, 42.VDD, 42.VDD_IO, 43.A1, 43.SENB/CS, 43.VDD, 43.VDD_IO, 44.A0, 44.A1, 44.SENB/CS, 44.VDD, 44.VDD_IO, 45.SENB/CS, 45.VDD, 45.VDD_IO, 46.A0, 46.SENB/CS, 46.VDD, 46.VDD_IO, 47.A1, 47.SENB/CS, 47.VDD, 47.VDD_IO, 48.A0, 48.A1, 48.SENB/CS, 48.VDD, 48.VDD_IO; also elsewhere on the board

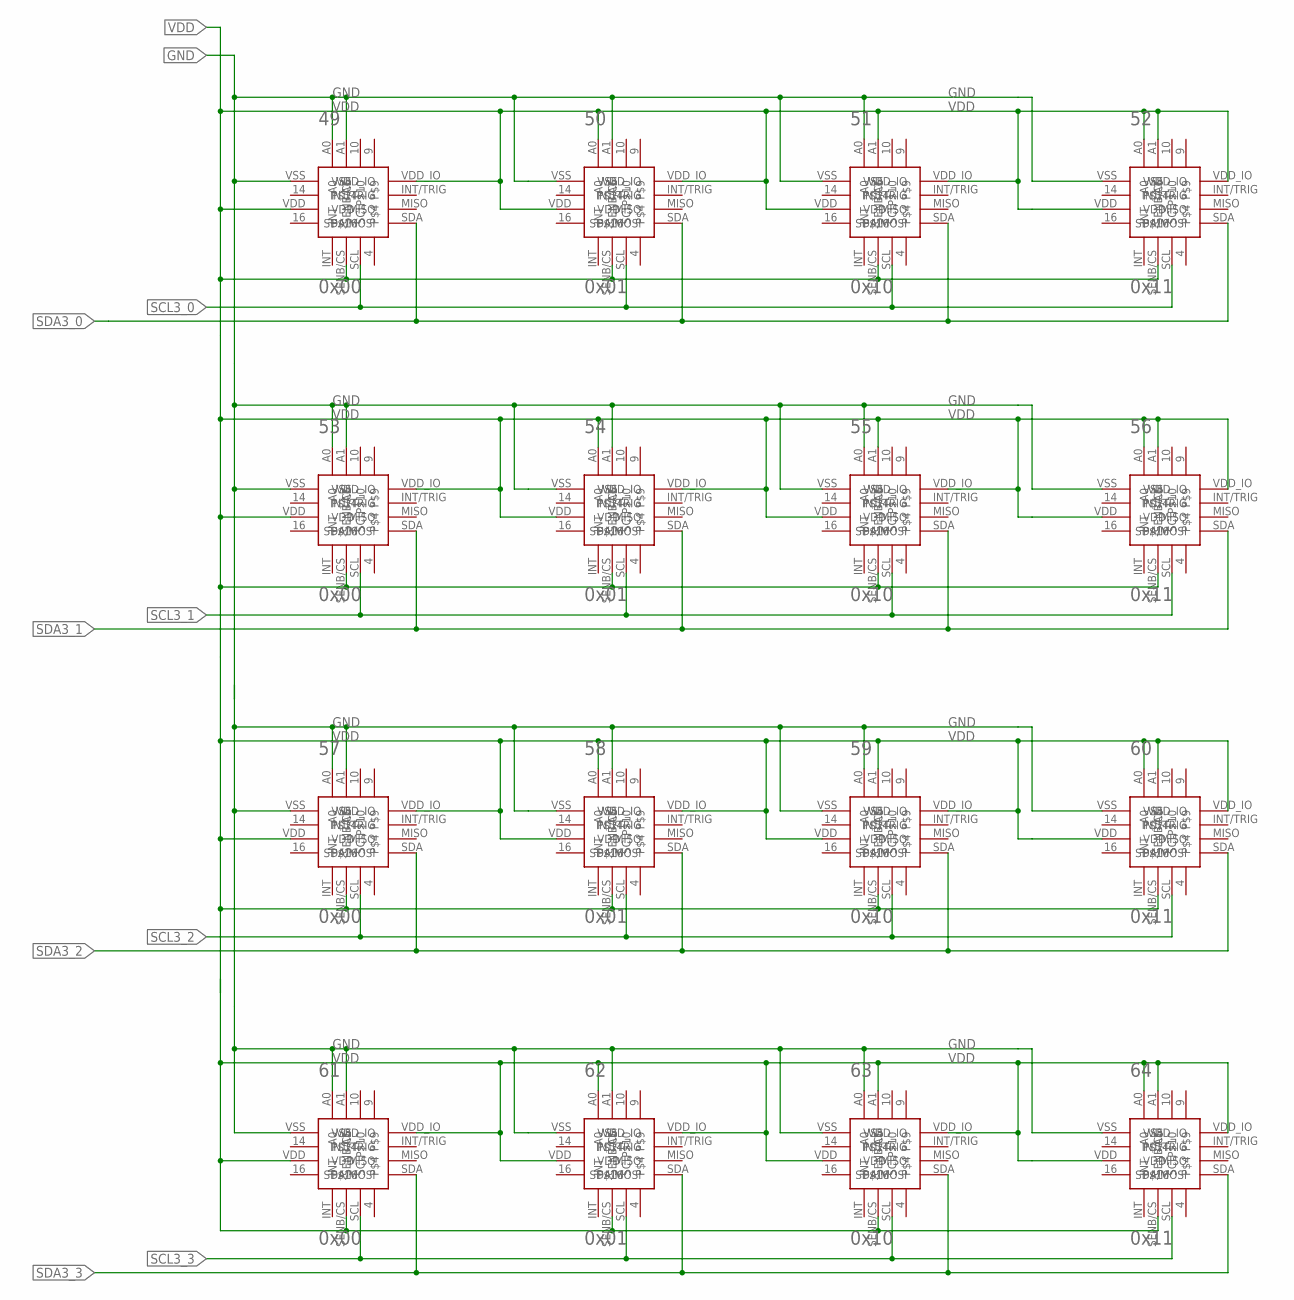
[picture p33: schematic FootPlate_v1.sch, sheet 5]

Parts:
49, 53, 57, 61: 0x00; MLX90393_PKG
50, 54, 58, 62: 0x01; MLX90393_PKG
51, 55, 59, 63: 0x10; MLX90393_PKG
52, 56, 60, 64: 0x11; MLX90393_PKG

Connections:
GND: 49.A0, 49.A1, 49.VSS, 50.A1, 50.VSS, 51.A0, 51.VSS, 52.VSS, 53.A0, 53.A1, 53.VSS, 54.A1, 54.VSS, 55.A0, 55.VSS, 56.VSS, 57.A0, 57.A1, 57.VSS, 58.A1, 58.VSS, 59.A0, 59.VSS, 60.VSS, 61.A0, 61.A1, 61.VSS, 62.A1, 62.VSS, 63.A0, 63.VSS, 64.VSS; also elsewhere on the board
SCL3_0: 49.SCL, 50.SCL, 51.SCL, 52.SCL; also elsewhere on the board
SCL3_1: 53.SCL, 54.SCL, 55.SCL, 56.SCL; also elsewhere on the board
SCL3_2: 57.SCL, 58.SCL, 59.SCL, 60.SCL; also elsewhere on the board
SCL3_3: 61.SCL, 62.SCL, 63.SCL, 64.SCL; also elsewhere on the board
SDA3_0: 49.SDA (SDA/MOSI), 50.SDA (SDA/MOSI), 51.SDA (SDA/MOSI), 52.SDA (SDA/MOSI); also elsewhere on the board
SDA3_1: 53.SDA (SDA/MOSI), 54.SDA (SDA/MOSI), 55.SDA (SDA/MOSI), 56.SDA (SDA/MOSI); also elsewhere on the board
SDA3_2: 57.SDA (SDA/MOSI), 58.SDA (SDA/MOSI), 59.SDA (SDA/MOSI), 60.SDA (SDA/MOSI); also elsewhere on the board
SDA3_3: 61.SDA (SDA/MOSI), 62.SDA (SDA/MOSI), 63.SDA (SDA/MOSI), 64.SDA (SDA/MOSI); also elsewhere on the board
VDD: 49.SENB/CS, 49.VDD, 49.VDD_IO, 50.A0, 50.SENB/CS, 50.VDD, 50.VDD_IO, 51.A1, 51.SENB/CS, 51.VDD, 51.VDD_IO, 52.A0, 52.A1, 52.SENB/CS, 52.VDD, 52.VDD_IO, 53.SENB/CS, 53.VDD, 53.VDD_IO, 54.A0, 54.SENB/CS, 54.VDD, 54.VDD_IO, 55.A1, 55.SENB/CS, 55.VDD, 55.VDD_IO, 56.A0, 56.A1, 56.SENB/CS, 56.VDD, 56.VDD_IO, 57.SENB/CS, 57.VDD, 57.VDD_IO, 58.A0, 58.SENB/CS, 58.VDD, 58.VDD_IO, 59.A1, 59.SENB/CS, 59.VDD, 59.VDD_IO, 60.A0, 60.A1, 60.SENB/CS, 60.VDD, 60.VDD_IO, 61.SENB/CS, 61.VDD, 61.VDD_IO, 62.A0, 62.SENB/CS, 62.VDD, 62.VDD_IO, 63.A1, 63.SENB/CS, 63.VDD, 63.VDD_IO, 64.A0, 64.A1, 64.SENB/CS, 64.VDD, 64.VDD_IO; also elsewhere on the board

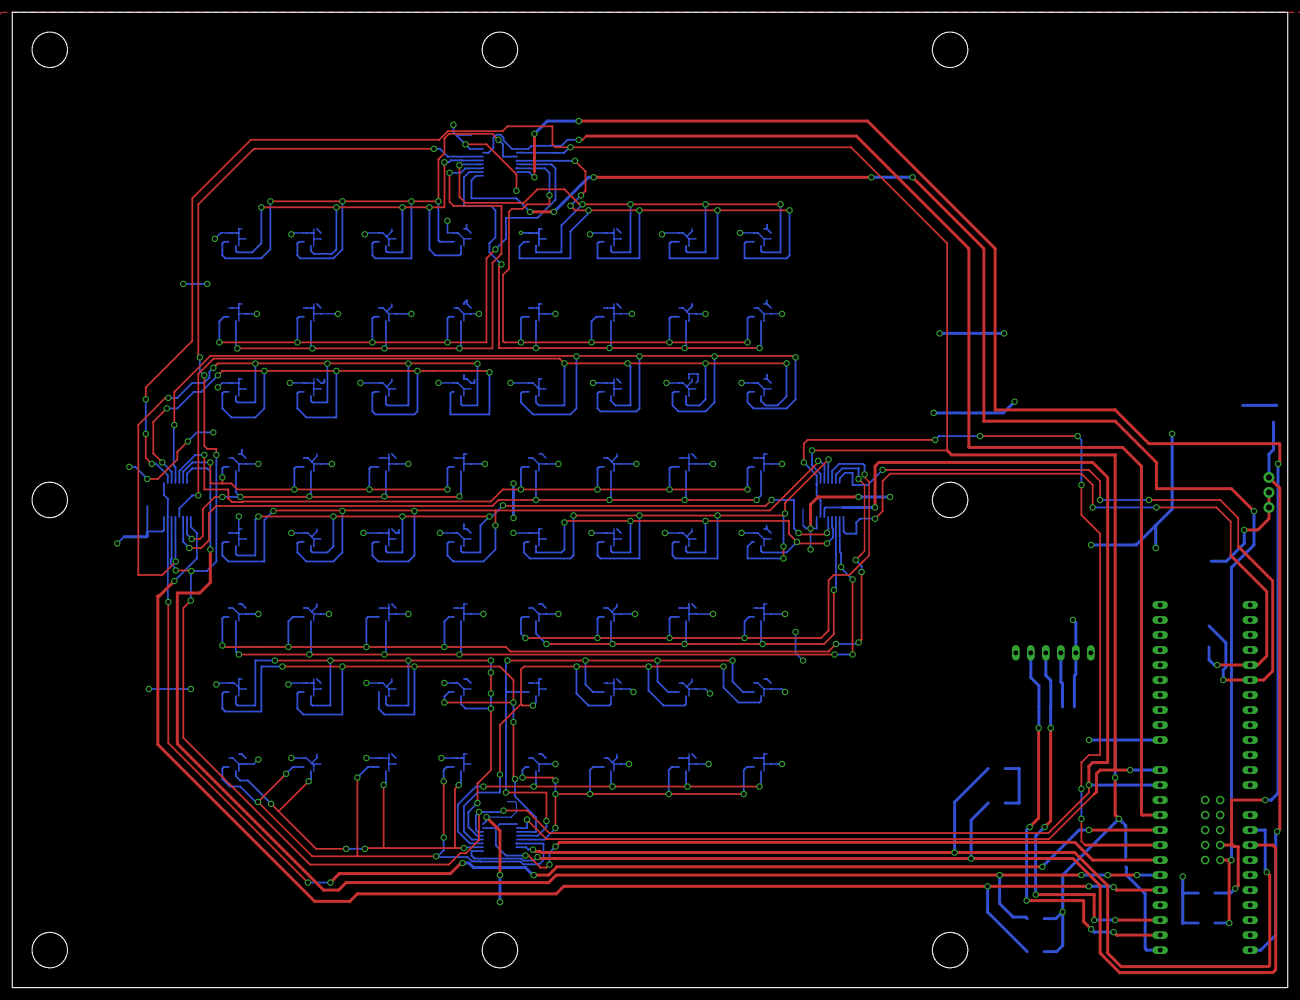
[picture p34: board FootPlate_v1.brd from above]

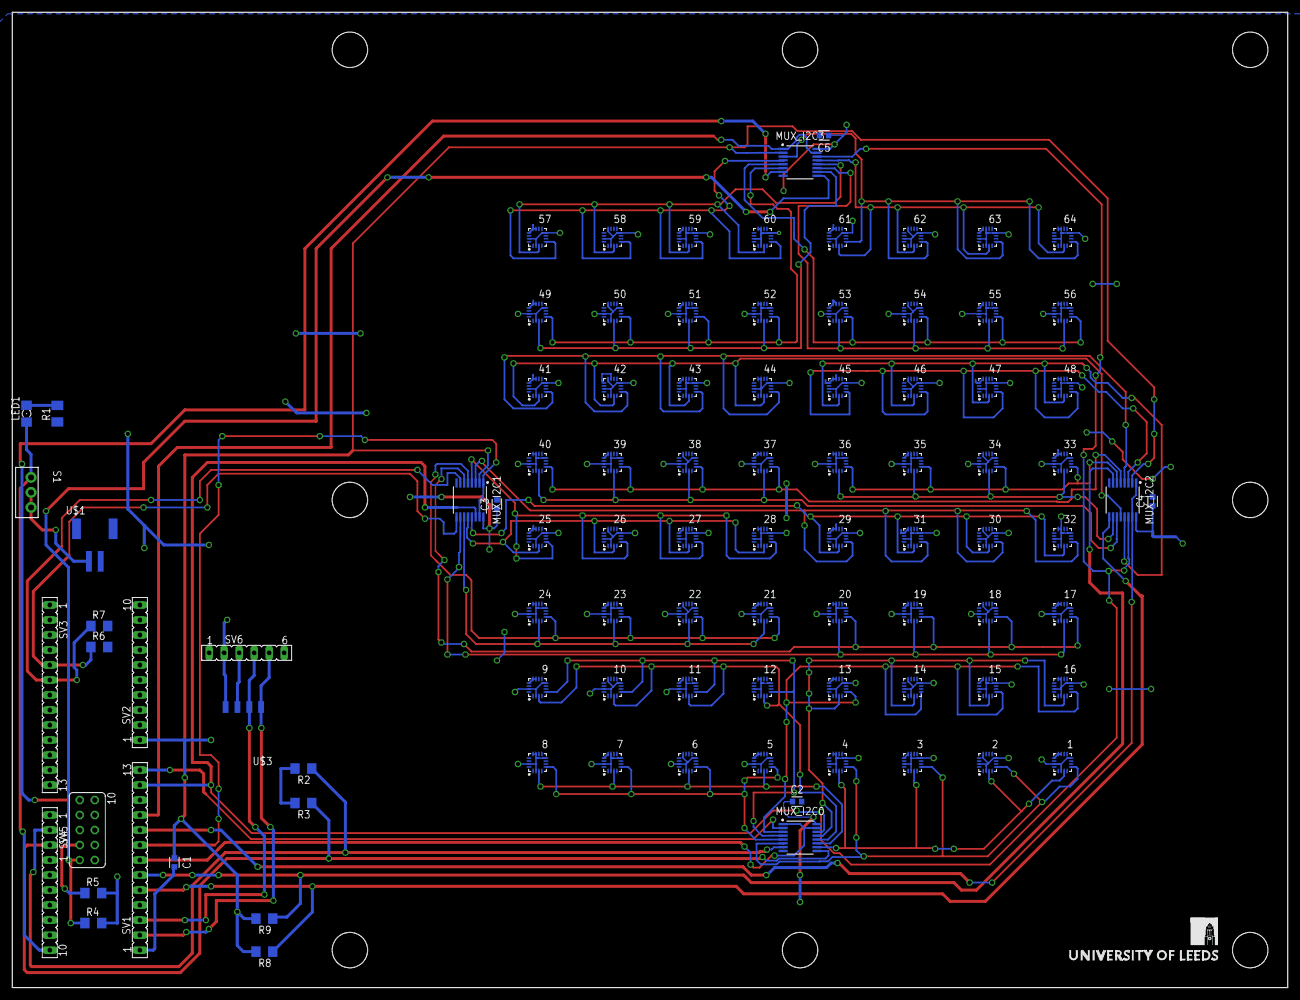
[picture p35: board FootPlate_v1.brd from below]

Board: 2 copper layers, 215.9 x 165.1 mm, 93 parts (93 on the bottom side), 53 nets.

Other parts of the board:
U$2: LOGO_LARGE

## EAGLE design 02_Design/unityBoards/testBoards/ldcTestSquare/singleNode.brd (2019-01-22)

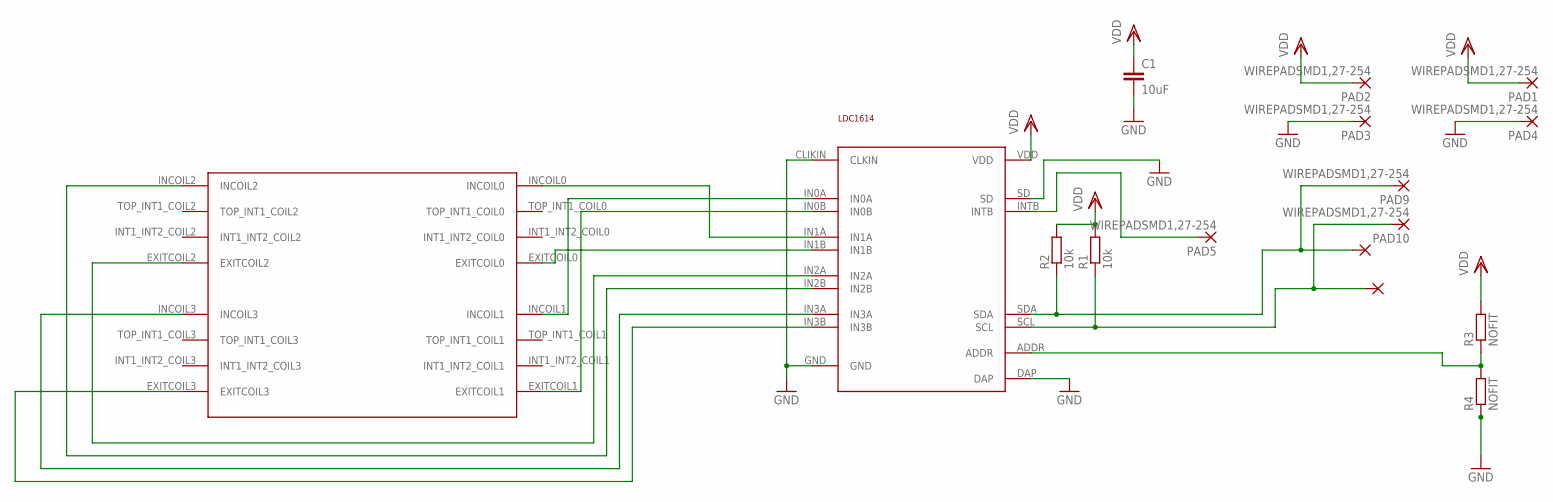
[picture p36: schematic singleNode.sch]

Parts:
C1: 10uF; C0402
PAD1, PAD2, PAD3, PAD4, PAD5, PAD6, PAD7, PAD9, PAD10: WIREPADSMD1,27-254; SMD1,27-2,54
R1, R2: 10k; R0402
R3, R4: NOFIT; R0201
U1: LDC1614; WQFN-16
U$2: FATSQUARE_GROUP; FAT_SQUARE

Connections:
ADDR: R3.1, R4.2, U1.ADDR
GND: C1.2, PAD3.1, PAD4.1, R4.1, U1.CLIKIN (CLKIN), U1.DAP, U1.GND, U1.SD
INTRPT: PAD5.1, U1.INTB
unnamed: U1.IN1A, U$2.INCOIL0
unnamed: U1.IN1B, U$2.EXITCOIL0
unnamed: U1.IN0A, U$2.INCOIL1
unnamed: U1.IN0B, U$2.EXITCOIL1
unnamed: U1.IN2A, U$2.EXITCOIL2
unnamed: U1.IN2B, U$2.INCOIL2
unnamed: U1.IN3A, U$2.INCOIL3
unnamed: U1.IN3B, U$2.EXITCOIL3
SCL: PAD7.1, PAD10.1, R1.1, U1.SCL
SDA: PAD6.1, PAD9.1, R2.1, U1.SDA
VDD: C1.1, PAD1.1, PAD2.1, R1.2, R2.2, R3.2, U1.VDD

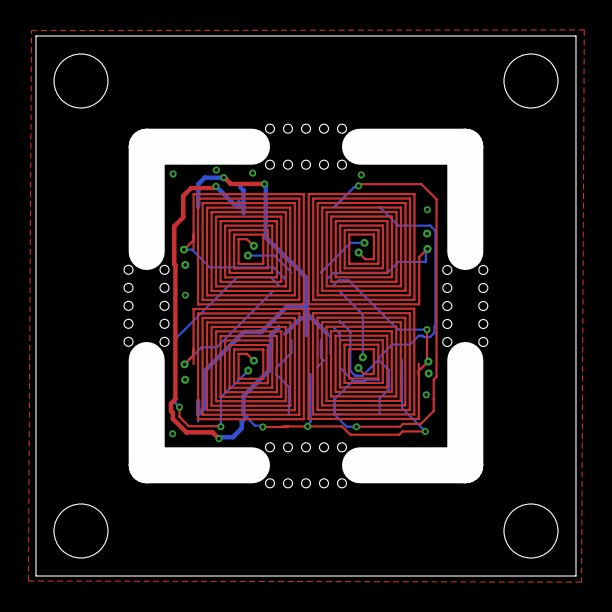
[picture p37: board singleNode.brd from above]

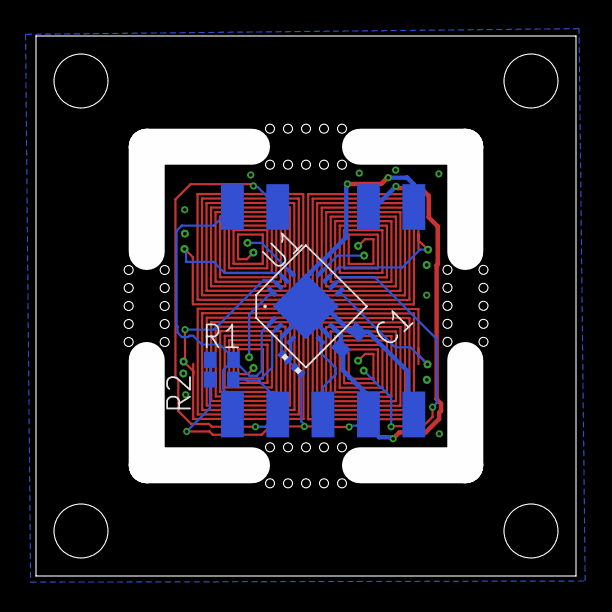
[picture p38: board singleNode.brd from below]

Board: 4 copper layers, 30.0 x 30.0 mm, 16 parts (15 on the bottom side), 14 nets.

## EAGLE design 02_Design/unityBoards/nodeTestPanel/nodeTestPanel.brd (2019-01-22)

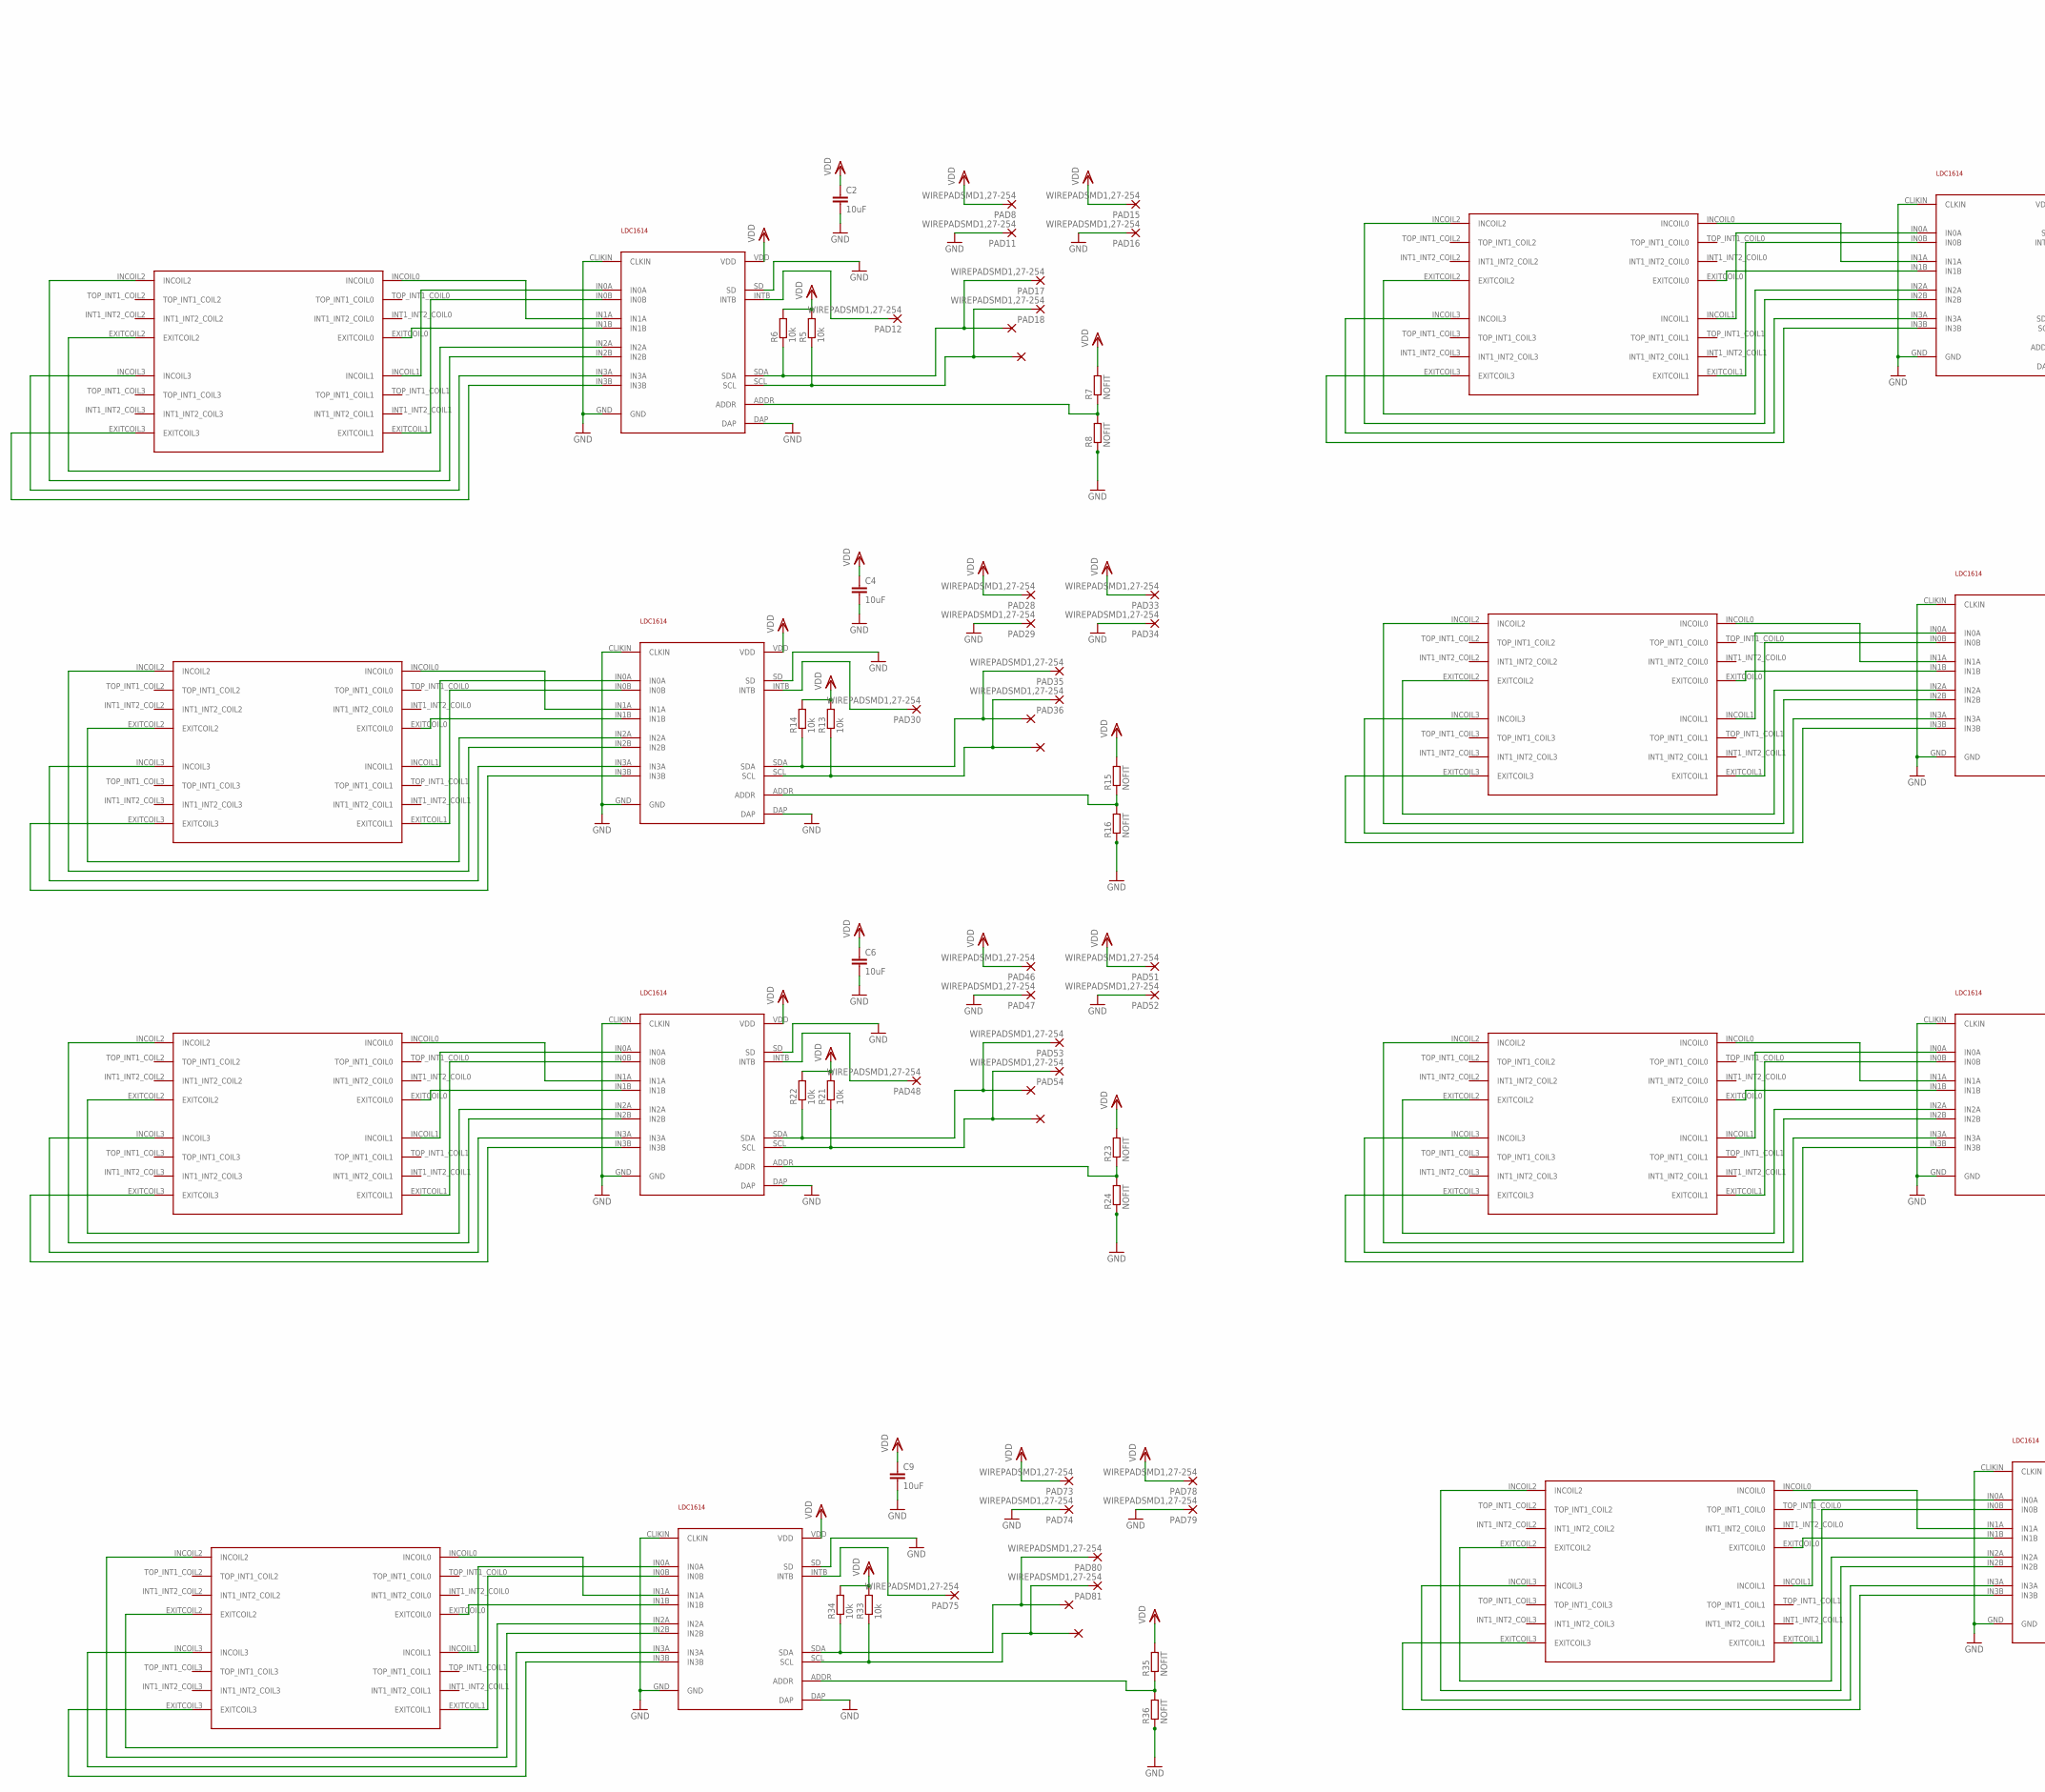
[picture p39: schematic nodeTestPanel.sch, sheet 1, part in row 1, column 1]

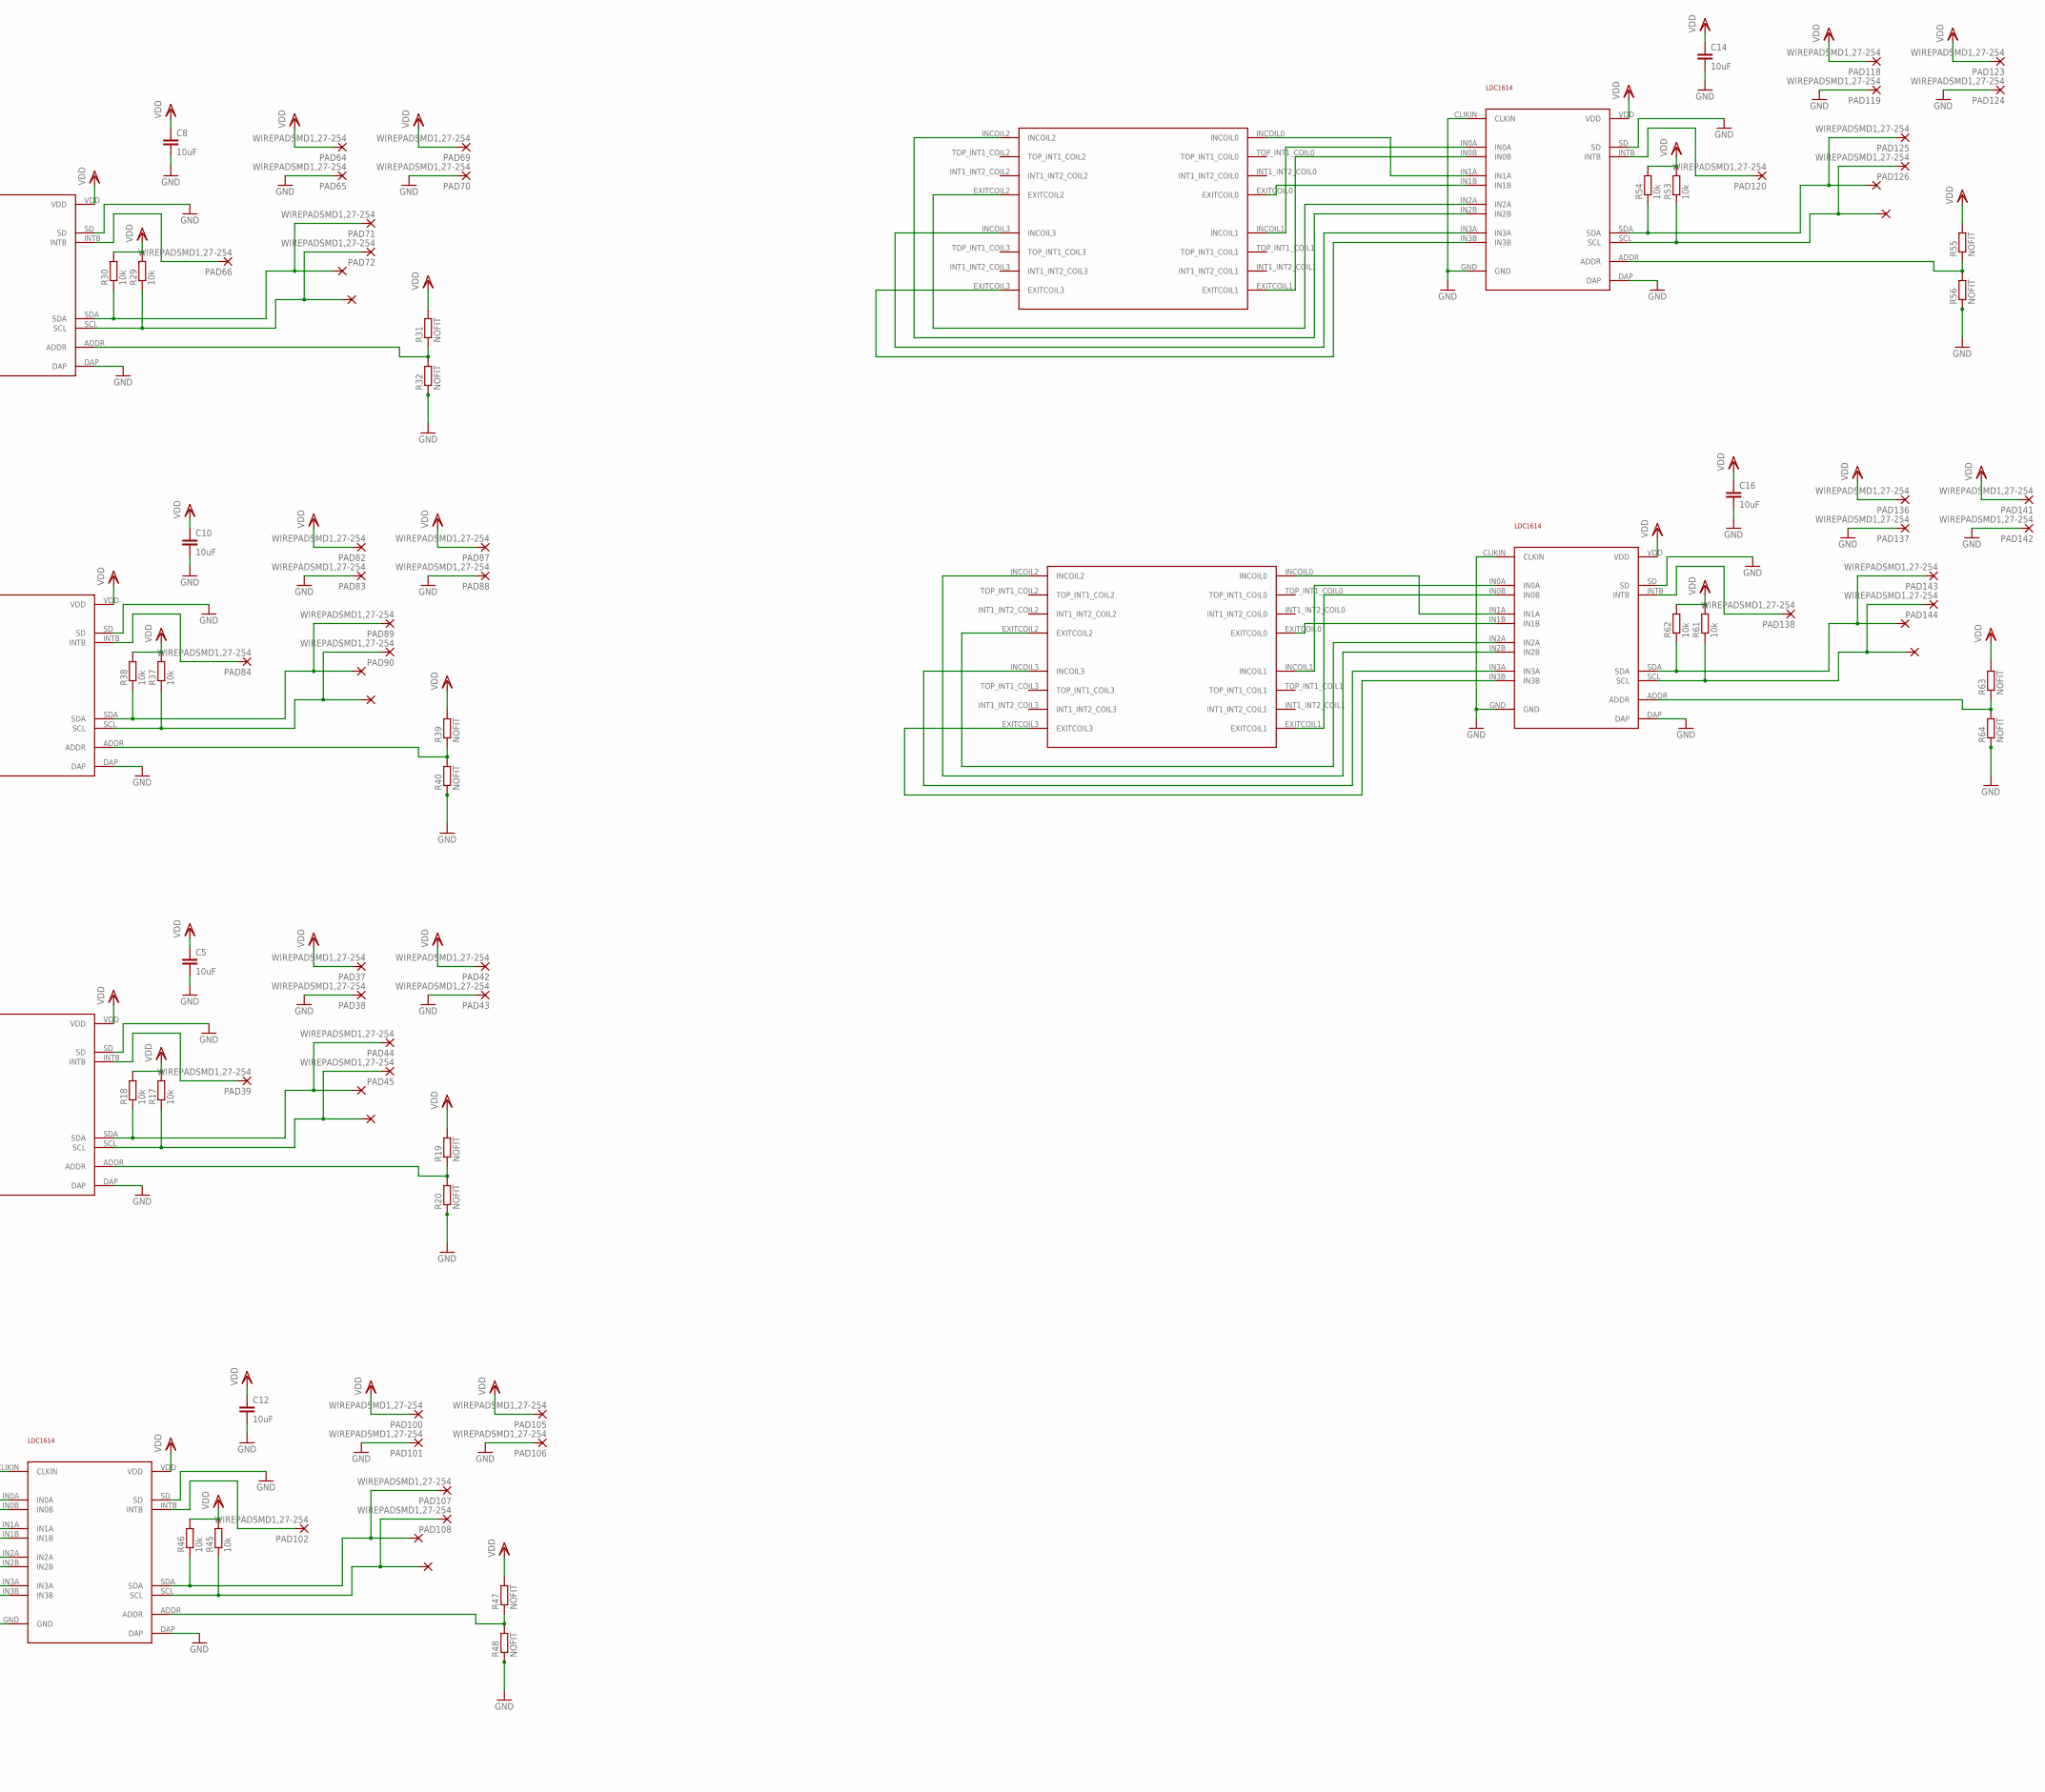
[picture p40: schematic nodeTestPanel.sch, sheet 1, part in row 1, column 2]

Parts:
C2, C4, C5, C6, C8, C9, C10, C12, C14, C16: 10uF; C0402
PAD8, PAD11, PAD12, PAD13, PAD14, PAD15, PAD16, PAD17, PAD18, PAD28, PAD29, PAD30, PAD31, PAD32, PAD33, PAD34, PAD35, PAD36, PAD37, PAD38, PAD39, PAD40, PAD41, PAD42, PAD43, PAD44, PAD45, PAD46, PAD47, PAD48, PAD49, PAD50, PAD51, PAD52, PAD53, PAD54, PAD64, PAD65, PAD66, PAD67, PAD68, PAD69, PAD70, PAD71, PAD72, PAD73, PAD74, PAD75, PAD76, PAD77, PAD78, PAD79, PAD80, PAD81, PAD82, PAD83, PAD84, PAD85, PAD86, PAD87, PAD88, PAD89, PAD90, PAD100, PAD101, PAD102, PAD103, PAD104, PAD105, PAD106, PAD107, PAD108, PAD118, PAD119, PAD120, PAD121, PAD122, PAD123, PAD124, PAD125, PAD126, PAD136, PAD137, PAD138, PAD139, PAD140, PAD141, PAD142, PAD143, PAD144: WIREPADSMD1,27-254; SMD1,27-2,54
R5, R6, R13, R14, R17, R18, R21, R22, R29, R30, R33, R34, R37, R38, R45, R46, R53, R54, R61, R62: 10k; R0402
R7, R8, R15, R16, R19, R20, R23, R24, R31, R32, R35, R36, R39, R40, R47, R48, R55, R56, R63, R64: NOFIT; R0201
U2, U4, U5, U6, U8, U9, U10, U12, U14, U16: LDC1614; WQFN-16
U$1, U$4, U$5, U$6, U$8, U$9, U$10, U$12, U$14, U$16: FATSQUARE_GROUP; FAT_SQUARE

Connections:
ADDR1: R7.1, R8.2, U2.ADDR
ADDR3: R15.1, R16.2, U4.ADDR
ADDR4: R19.1, R20.2, U5.ADDR
ADDR5: R23.1, R24.2, U6.ADDR
ADDR7: R31.1, R32.2, U8.ADDR
ADDR8: R35.1, R36.2, U9.ADDR
ADDR9: R39.1, R40.2, U10.ADDR
ADDR11: R47.1, R48.2, U12.ADDR
ADDR13: R55.1, R56.2, U14.ADDR
ADDR15: R63.1, R64.2, U16.ADDR
GND: C2.2, C4.2, C5.2, C6.2, C8.2, C9.2, C10.2, C12.2, C14.2, C16.2, PAD11.1, PAD16.1, PAD29.1, PAD34.1, PAD38.1, PAD43.1, PAD47.1, PAD52.1, PAD65.1, PAD70.1, PAD74.1, PAD79.1, PAD83.1, PAD88.1, PAD101.1, PAD106.1, PAD119.1, PAD124.1, PAD137.1, PAD142.1, R8.1, R16.1, R20.1, R24.1, R32.1, R36.1, R40.1, R48.1, R56.1, R64.1, U2.CLIKIN (CLKIN), U2.DAP, U2.GND, U2.SD, U4.CLIKIN (CLKIN), U4.DAP, U4.GND, U4.SD, U5.CLIKIN (CLKIN), U5.DAP, U5.GND, U5.SD, U6.CLIKIN (CLKIN), U6.DAP, U6.GND, U6.SD, U8.CLIKIN (CLKIN), U8.DAP, U8.GND, U8.SD, U9.CLIKIN (CLKIN), U9.DAP, U9.GND, U9.SD, U10.CLIKIN (CLKIN), U10.DAP, U10.GND, U10.SD, U12.CLIKIN (CLKIN), U12.DAP, U12.GND, U12.SD, U14.CLIKIN (CLKIN), U14.DAP, U14.GND, U14.SD, U16.CLIKIN (CLKIN), U16.DAP, U16.GND, U16.SD; also elsewhere on the board
INTRPT1: PAD12.1, U2.INTB
INTRPT3: PAD30.1, U4.INTB
INTRPT4: PAD39.1, U5.INTB
INTRPT5: PAD48.1, U6.INTB
INTRPT7: PAD66.1, U8.INTB
INTRPT8: PAD75.1, U9.INTB
INTRPT9: PAD84.1, U10.INTB
INTRPT11: PAD102.1, U12.INTB
INTRPT13: PAD120.1, U14.INTB
INTRPT15: PAD138.1, U16.INTB
unnamed: U2.IN1B, U$1.EXITCOIL0
unnamed: U2.IN0A, U$1.INCOIL1
unnamed: U2.IN0B, U$1.EXITCOIL1
unnamed: U2.IN2A, U$1.EXITCOIL2
unnamed: U2.IN2B, U$1.INCOIL2
unnamed: U2.IN3A, U$1.INCOIL3
unnamed: U2.IN3B, U$1.EXITCOIL3
unnamed: U2.IN1A, U$1.INCOIL0
unnamed: U4.IN1B, U$4.EXITCOIL0
unnamed: U4.IN0A, U$4.INCOIL1
unnamed: U4.IN0B, U$4.EXITCOIL1
unnamed: U4.IN2A, U$4.EXITCOIL2
unnamed: U4.IN2B, U$4.INCOIL2
unnamed: U4.IN3A, U$4.INCOIL3
unnamed: U4.IN3B, U$4.EXITCOIL3
unnamed: U4.IN1A, U$4.INCOIL0
unnamed: U5.IN1B, U$5.EXITCOIL0
unnamed: U5.IN0A, U$5.INCOIL1
unnamed: U5.IN0B, U$5.EXITCOIL1
unnamed: U5.IN2A, U$5.EXITCOIL2
unnamed: U5.IN2B, U$5.INCOIL2
unnamed: U5.IN3A, U$5.INCOIL3
unnamed: U5.IN3B, U$5.EXITCOIL3
unnamed: U5.IN1A, U$5.INCOIL0
unnamed: U6.IN1B, U$6.EXITCOIL0
unnamed: U6.IN0A, U$6.INCOIL1
unnamed: U6.IN0B, U$6.EXITCOIL1
unnamed: U6.IN2A, U$6.EXITCOIL2
unnamed: U6.IN2B, U$6.INCOIL2
unnamed: U6.IN3A, U$6.INCOIL3
unnamed: U6.IN3B, U$6.EXITCOIL3
unnamed: U6.IN1A, U$6.INCOIL0
unnamed: U8.IN1B, U$8.EXITCOIL0
unnamed: U8.IN0A, U$8.INCOIL1
unnamed: U8.IN0B, U$8.EXITCOIL1
unnamed: U8.IN2A, U$8.EXITCOIL2
unnamed: U8.IN2B, U$8.INCOIL2
unnamed: U8.IN3A, U$8.INCOIL3
unnamed: U8.IN3B, U$8.EXITCOIL3
unnamed: U8.IN1A, U$8.INCOIL0
unnamed: U9.IN1B, U$9.EXITCOIL0
unnamed: U9.IN0A, U$9.INCOIL1
unnamed: U9.IN0B, U$9.EXITCOIL1
unnamed: U9.IN2A, U$9.EXITCOIL2
unnamed: U9.IN2B, U$9.INCOIL2
unnamed: U9.IN3A, U$9.INCOIL3
unnamed: U9.IN3B, U$9.EXITCOIL3
unnamed: U9.IN1A, U$9.INCOIL0
unnamed: U10.IN1B, U$10.EXITCOIL0
unnamed: U10.IN0A, U$10.INCOIL1
unnamed: U10.IN0B, U$10.EXITCOIL1
unnamed: U10.IN2A, U$10.EXITCOIL2
unnamed: U10.IN2B, U$10.INCOIL2
unnamed: U10.IN3A, U$10.INCOIL3
unnamed: U10.IN3B, U$10.EXITCOIL3
unnamed: U10.IN1A, U$10.INCOIL0
unnamed: U12.IN1B, U$12.EXITCOIL0
unnamed: U12.IN0A, U$12.INCOIL1
unnamed: U12.IN0B, U$12.EXITCOIL1
unnamed: U12.IN2A, U$12.EXITCOIL2
unnamed: U12.IN2B, U$12.INCOIL2
unnamed: U12.IN3A, U$12.INCOIL3
unnamed: U12.IN3B, U$12.EXITCOIL3
unnamed: U12.IN1A, U$12.INCOIL0
unnamed: U14.IN1B, U$14.EXITCOIL0
unnamed: U14.IN0A, U$14.INCOIL1
unnamed: U14.IN0B, U$14.EXITCOIL1
unnamed: U14.IN2A, U$14.EXITCOIL2
unnamed: U14.IN2B, U$14.INCOIL2
unnamed: U14.IN3A, U$14.INCOIL3
unnamed: U14.IN3B, U$14.EXITCOIL3
unnamed: U14.IN1A, U$14.INCOIL0
unnamed: U16.IN1B, U$16.EXITCOIL0
unnamed: U16.IN0A, U$16.INCOIL1
unnamed: U16.IN0B, U$16.EXITCOIL1
unnamed: U16.IN2A, U$16.EXITCOIL2
unnamed: U16.IN2B, U$16.INCOIL2
unnamed: U16.IN3A, U$16.INCOIL3
unnamed: U16.IN3B, U$16.EXITCOIL3
unnamed: U16.IN1A, U$16.INCOIL0
SCL1: PAD14.1, PAD18.1, R5.1, U2.SCL
SCL3: PAD32.1, PAD36.1, R13.1, U4.SCL
SCL4: PAD41.1, PAD45.1, R17.1, U5.SCL
SCL5: PAD50.1, PAD54.1, R21.1, U6.SCL
SCL7: PAD68.1, PAD72.1, R29.1, U8.SCL
SCL8: PAD77.1, PAD81.1, R33.1, U9.SCL
SCL9: PAD86.1, PAD90.1, R37.1, U10.SCL
SCL11: PAD104.1, PAD108.1, R45.1, U12.SCL
SCL13: PAD122.1, PAD126.1, R53.1, U14.SCL
SCL15: PAD140.1, PAD144.1, R61.1, U16.SCL
SDA1: PAD13.1, PAD17.1, R6.1, U2.SDA
SDA3: PAD31.1, PAD35.1, R14.1, U4.SDA
SDA4: PAD40.1, PAD44.1, R18.1, U5.SDA
SDA5: PAD49.1, PAD53.1, R22.1, U6.SDA
SDA7: PAD67.1, PAD71.1, R30.1, U8.SDA
SDA8: PAD76.1, PAD80.1, R34.1, U9.SDA
SDA9: PAD85.1, PAD89.1, R38.1, U10.SDA
SDA11: PAD103.1, PAD107.1, R46.1, U12.SDA
SDA13: PAD121.1, PAD125.1, R54.1, U14.SDA
SDA15: PAD139.1, PAD143.1, R62.1, U16.SDA
VDD: C2.1, C4.1, C5.1, C6.1, C8.1, C9.1, C10.1, C12.1, C14.1, C16.1, PAD8.1, PAD15.1, PAD28.1, PAD33.1, PAD37.1, PAD42.1, PAD46.1, PAD51.1, PAD64.1, PAD69.1, PAD73.1, PAD78.1, PAD82.1, PAD87.1, PAD100.1, PAD105.1, PAD118.1, PAD123.1, PAD136.1, PAD141.1, R5.2, R6.2, R7.2, R13.2, R14.2, R15.2, R17.2, R18.2, R19.2, R21.2, R22.2, R23.2, R29.2, R30.2, R31.2, R33.2, R34.2, R35.2, R37.2, R38.2, R39.2, R45.2, R46.2, R47.2, R53.2, R54.2, R55.2, R61.2, R62.2, R63.2, U2.VDD, U4.VDD, U5.VDD, U6.VDD, U8.VDD, U9.VDD, U10.VDD, U12.VDD, U14.VDD, U16.VDD; also elsewhere on the board

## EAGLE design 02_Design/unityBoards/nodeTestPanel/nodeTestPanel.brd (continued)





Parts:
C19, C21, C23, C25, C27, C29, C31, C33, C35, C37: 10uF; C0402
PAD165, PAD166, PAD167, PAD168, PAD169, PAD170, PAD171, PAD172, PAD173, PAD174, PAD185, PAD186, PAD187, PAD188, PAD189, PAD190, PAD191, PAD192, PAD193, PAD194, PAD205, PAD206, PAD207, PAD208, PAD209, PAD210, PAD211, PAD212, PAD213, PAD214, PAD225, PAD226, PAD227, PAD228, PAD229, PAD230, PAD231, PAD232, PAD233, PAD234, PAD245, PAD246, PAD247, PAD248, PAD249, PAD250, PAD251, PAD252, PAD253, PAD254, PAD265, PAD266, PAD267, PAD268, PAD269, PAD270, PAD271, PAD272, PAD273, PAD274, PAD285, PAD286, PAD287, PAD288, PAD289, PAD290, PAD291, PAD292, PAD293, PAD294, PAD305, PAD306, PAD307, PAD308, PAD309, PAD310, PAD311, PAD312, PAD313, PAD314, PAD325, PAD326, PAD327, PAD328, PAD329, PAD330, PAD331, PAD332, PAD333, PAD334, PAD345, PAD346, PAD347, PAD348, PAD349, PAD350, PAD351, PAD352, PAD353, PAD354: WIREPADSMD1,27-254; SMD1,27-2,54
R73, R74, R81, R82, R89, R90, R97, R98, R105, R106, R113, R114, R121, R122, R129, R130, R137, R138, R145, R146: 10k; R0402
R75, R76, R83, R84, R91, R92, R99, R100, R107, R108, R115, R116, R123, R124, R131, R132, R139, R140, R147, R148: NOFIT; R0201
U19, U21, U23, U25, U27, U29, U31, U33, U35, U37: LDC1614; WQFN-16
U$19, U$21, U$23, U$25, U$27, U$29, U$31, U$33, U$35, U$37: FATFAN_GROUP; FAT_FAN

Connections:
ADDR18: R75.1, R76.2, U19.ADDR
ADDR20: R83.1, R84.2, U21.ADDR
ADDR22: R91.1, R92.2, U23.ADDR
ADDR24: R99.1, R100.2, U25.ADDR
ADDR26: R107.1, R108.2, U27.ADDR
ADDR28: R115.1, R116.2, U29.ADDR
ADDR30: R123.1, R124.2, U31.ADDR
ADDR32: R131.1, R132.2, U33.ADDR
ADDR34: R139.1, R140.2, U35.ADDR
ADDR36: R147.1, R148.2, U37.ADDR
GND: C19.2, C21.2, C23.2, C25.2, C27.2, C29.2, C31.2, C33.2, C35.2, C37.2, PAD166.1, PAD171.1, PAD186.1, PAD191.1, PAD206.1, PAD211.1, PAD226.1, PAD231.1, PAD246.1, PAD251.1, PAD266.1, PAD271.1, PAD286.1, PAD291.1, PAD306.1, PAD311.1, PAD326.1, PAD331.1, PAD346.1, PAD351.1, R76.1, R84.1, R92.1, R100.1, R108.1, R116.1, R124.1, R132.1, R140.1, R148.1, U19.CLIKIN (CLKIN), U19.DAP, U19.GND, U19.SD, U21.CLIKIN (CLKIN), U21.DAP, U21.GND, U21.SD, U23.CLIKIN (CLKIN), U23.DAP, U23.GND, U23.SD, U25.CLIKIN (CLKIN), U25.DAP, U25.GND, U25.SD, U27.CLIKIN (CLKIN), U27.DAP, U27.GND, U27.SD, U29.CLIKIN (CLKIN), U29.DAP, U29.GND, U29.SD, U31.CLIKIN (CLKIN), U31.DAP, U31.GND, U31.SD, U33.CLIKIN (CLKIN), U33.DAP, U33.GND, U33.SD, U35.CLIKIN (CLKIN), U35.DAP, U35.GND, U35.SD, U37.CLIKIN (CLKIN), U37.DAP, U37.GND, U37.SD; also elsewhere on the board
INTRPT18: PAD167.1, PAD172.1, U19.INTB
INTRPT20: PAD187.1, PAD192.1, U21.INTB
INTRPT22: PAD207.1, PAD212.1, U23.INTB
INTRPT24: PAD227.1, PAD232.1, U25.INTB
INTRPT26: PAD247.1, PAD252.1, U27.INTB
INTRPT28: PAD267.1, PAD272.1, U29.INTB
INTRPT30: PAD287.1, PAD292.1, U31.INTB
INTRPT32: PAD307.1, PAD312.1, U33.INTB
INTRPT34: PAD327.1, PAD332.1, U35.INTB
INTRPT36: PAD347.1, PAD352.1, U37.INTB
unnamed: U19.IN1B, U$19.EXITCOIL0
unnamed: U19.IN0A, U$19.INCOIL1
unnamed: U19.IN0B, U$19.EXITCOIL1
unnamed: U19.IN2A, U$19.EXITCOIL2B (EXITCOIL2)
unnamed: U19.IN2B, U$19.INCOIL2B (INCOIL2)
unnamed: U19.IN3A, U$19.INCOIL3
unnamed: U19.IN3B, U$19.EXITCOIL3
unnamed: U19.IN1A, U$19.INCOIL0
unnamed: U21.IN1B, U$21.EXITCOIL0
unnamed: U21.IN0A, U$21.INCOIL1
unnamed: U21.IN0B, U$21.EXITCOIL1
unnamed: U21.IN2A, U$21.EXITCOIL2B (EXITCOIL2)
unnamed: U21.IN2B, U$21.INCOIL2B (INCOIL2)
unnamed: U21.IN3A, U$21.INCOIL3
unnamed: U21.IN3B, U$21.EXITCOIL3
unnamed: U21.IN1A, U$21.INCOIL0
unnamed: U23.IN1B, U$23.EXITCOIL0
unnamed: U23.IN0A, U$23.INCOIL1
unnamed: U23.IN0B, U$23.EXITCOIL1
unnamed: U23.IN2A, U$23.EXITCOIL2B (EXITCOIL2)
unnamed: U23.IN2B, U$23.INCOIL2B (INCOIL2)
unnamed: U23.IN3A, U$23.INCOIL3
unnamed: U23.IN3B, U$23.EXITCOIL3
unnamed: U23.IN1A, U$23.INCOIL0
unnamed: U25.IN1B, U$25.EXITCOIL0
unnamed: U25.IN0A, U$25.INCOIL1
unnamed: U25.IN0B, U$25.EXITCOIL1
unnamed: U25.IN2A, U$25.EXITCOIL2B (EXITCOIL2)
unnamed: U25.IN2B, U$25.INCOIL2B (INCOIL2)
unnamed: U25.IN3A, U$25.INCOIL3
unnamed: U25.IN3B, U$25.EXITCOIL3
unnamed: U25.IN1A, U$25.INCOIL0
unnamed: U27.IN1B, U$27.EXITCOIL0
unnamed: U27.IN0A, U$27.INCOIL1
unnamed: U27.IN0B, U$27.EXITCOIL1
unnamed: U27.IN2A, U$27.EXITCOIL2B (EXITCOIL2)
unnamed: U27.IN2B, U$27.INCOIL2B (INCOIL2)
unnamed: U27.IN3A, U$27.INCOIL3
unnamed: U27.IN3B, U$27.EXITCOIL3
unnamed: U27.IN1A, U$27.INCOIL0
unnamed: U29.IN1B, U$29.EXITCOIL0
unnamed: U29.IN0A, U$29.INCOIL1
unnamed: U29.IN0B, U$29.EXITCOIL1
unnamed: U29.IN2A, U$29.EXITCOIL2B (EXITCOIL2)
unnamed: U29.IN2B, U$29.INCOIL2B (INCOIL2)
unnamed: U29.IN3A, U$29.INCOIL3
unnamed: U29.IN3B, U$29.EXITCOIL3
unnamed: U29.IN1A, U$29.INCOIL0
unnamed: U31.IN1B, U$31.EXITCOIL0
unnamed: U31.IN0A, U$31.INCOIL1
unnamed: U31.IN0B, U$31.EXITCOIL1
unnamed: U31.IN2A, U$31.EXITCOIL2B (EXITCOIL2)
unnamed: U31.IN2B, U$31.INCOIL2B (INCOIL2)
unnamed: U31.IN3A, U$31.INCOIL3
unnamed: U31.IN3B, U$31.EXITCOIL3
unnamed: U31.IN1A, U$31.INCOIL0
unnamed: U33.IN1B, U$33.EXITCOIL0
unnamed: U33.IN0A, U$33.INCOIL1
unnamed: U33.IN0B, U$33.EXITCOIL1
unnamed: U33.IN2A, U$33.EXITCOIL2B (EXITCOIL2)
unnamed: U33.IN2B, U$33.INCOIL2B (INCOIL2)
unnamed: U33.IN3A, U$33.INCOIL3
unnamed: U33.IN3B, U$33.EXITCOIL3
unnamed: U33.IN1A, U$33.INCOIL0
unnamed: U35.IN1B, U$35.EXITCOIL0
unnamed: U35.IN0A, U$35.INCOIL1
unnamed: U35.IN0B, U$35.EXITCOIL1
unnamed: U35.IN2A, U$35.EXITCOIL2B (EXITCOIL2)
unnamed: U35.IN2B, U$35.INCOIL2B (INCOIL2)
unnamed: U35.IN3A, U$35.INCOIL3
unnamed: U35.IN3B, U$35.EXITCOIL3
unnamed: U35.IN1A, U$35.INCOIL0
unnamed: U37.IN1B, U$37.EXITCOIL0
unnamed: U37.IN0A, U$37.INCOIL1
unnamed: U37.IN0B, U$37.EXITCOIL1
unnamed: U37.IN2A, U$37.EXITCOIL2B (EXITCOIL2)
unnamed: U37.IN2B, U$37.INCOIL2B (INCOIL2)
unnamed: U37.IN3A, U$37.INCOIL3
unnamed: U37.IN3B, U$37.EXITCOIL3
unnamed: U37.IN1A, U$37.INCOIL0
SCL18: PAD169.1, PAD174.1, R73.1, U19.SCL
SCL20: PAD189.1, PAD194.1, R81.1, U21.SCL
SCL22: PAD209.1, PAD214.1, R89.1, U23.SCL
SCL24: PAD229.1, PAD234.1, R97.1, U25.SCL
SCL26: PAD249.1, PAD254.1, R105.1, U27.SCL
SCL28: PAD269.1, PAD274.1, R113.1, U29.SCL
SCL30: PAD289.1, PAD294.1, R121.1, U31.SCL
SCL32: PAD309.1, PAD314.1, R129.1, U33.SCL
SCL34: PAD329.1, PAD334.1, R137.1, U35.SCL
SCL36: PAD349.1, PAD354.1, R145.1, U37.SCL
SDA18: PAD168.1, PAD173.1, R74.1, U19.SDA
SDA20: PAD188.1, PAD193.1, R82.1, U21.SDA
SDA22: PAD208.1, PAD213.1, R90.1, U23.SDA
SDA24: PAD228.1, PAD233.1, R98.1, U25.SDA
SDA26: PAD248.1, PAD253.1, R106.1, U27.SDA
SDA28: PAD268.1, PAD273.1, R114.1, U29.SDA
SDA30: PAD288.1, PAD293.1, R122.1, U31.SDA
SDA32: PAD308.1, PAD313.1, R130.1, U33.SDA
SDA34: PAD328.1, PAD333.1, R138.1, U35.SDA
SDA36: PAD348.1, PAD353.1, R146.1, U37.SDA
VDD: C19.1, C21.1, C23.1, C25.1, C27.1, C29.1, C31.1, C33.1, C35.1, C37.1, PAD165.1, PAD170.1, PAD185.1, PAD190.1, PAD205.1, PAD210.1, PAD225.1, PAD230.1, PAD245.1, PAD250.1, PAD265.1, PAD270.1, PAD285.1, PAD290.1, PAD305.1, PAD310.1, PAD325.1, PAD330.1, PAD345.1, PAD350.1, R73.2, R74.2, R75.2, R81.2, R82.2, R83.2, R89.2, R90.2, R91.2, R97.2, R98.2, R99.2, R105.2, R106.2, R107.2, R113.2, R114.2, R115.2, R121.2, R122.2, R123.2, R129.2, R130.2, R131.2, R137.2, R138.2, R139.2, R145.2, R146.2, R147.2, U19.VDD, U21.VDD, U23.VDD, U25.VDD, U27.VDD, U29.VDD, U31.VDD, U33.VDD, U35.VDD, U37.VDD; also elsewhere on the board



Board: 4 copper layers, 160.0 x 205.0 mm, 330 parts (310 on the bottom side), 242 nets.

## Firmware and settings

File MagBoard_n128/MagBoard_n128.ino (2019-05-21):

 // MagBoard n128 Test
////////////////////////////////////
// v1 of full platform by Pete Culmer
// 
///////////////////////////////////

//include MagLIB - for access to high and low level chip functions
#include <MagLib.h>

// MagLIB Defs
MagLib device; //Change this to MLX for readability
#define addressPacket 0x0F0E0D0C
//#define addressPacket 0x0F0E0D0C //UPDATE WITH NEW ADDRESSES HERE

char buffer[NODE_64];
char stream_packet_header[3];
int mux[2] = {10, 11};
uint8_t Select_ZYX = 0xE;

//MLX CHIP SETTINGS
uint8_t GAIN_SEL = 0x00;  // 
uint8_t RES_XYZ = 0x01;  // to match NN training 29/04/2019
uint8_t DIG_FILT = 0x1;
uint8_t OSR = 0x1;

//COMMS SETTINGS //see SD library Example (from Teensy)
int serial_baudrate = 115200;
const int ledPin = 13; //used to signify comms
bool status_led = false;

void setup() {
  
  pinMode(ledPin, OUTPUT);
  digitalWrite(ledPin, LOW);

  //Initiate USB Serial + BT comms
  Serial.begin(serial_baudrate);
  
  //Wait for USB Serial to be available
  while (!Serial) {
    delay(10);
  }
  digitalWrite(ledPin, HIGH); //Signify when Comms active
  delay(1000);
  digitalWrite(ledPin, LOW);
  
  Serial.println("MagBOARDv128 is Alive!"); //Signify system active and print version info
  Serial.println(__FILE__);
  Serial.println(__DATE__);
  Serial.println(__TIME__);
  
  //Init i2c comms 
  device.initCommunication(115200, 0);
  Serial.println("\nInitialised I2C Bus");
  
      
  //Initialise I2C Ports
  device.init16Nodes(addressPacket, buffer, Select_ZYX, mux, 0, GAIN_SEL, RES_XYZ, DIG_FILT, OSR);
  //device.init64Nodes(addressPacket, buffer, Select_ZYX, mux, GAIN_SEL, RES_XYZ, DIG_FILT, OSR);
  
  Serial.println("\nInitialised Line");
  
  delay(500);

  //i2c reads from hear onwards will be non-blocking
  Wire.setOpMode(I2C_OP_MODE_ISR);
//  Wire1.setOpMode(I2C_OP_MODE_ISR);
//  Wire2.setOpMode(I2C_OP_MODE_ISR);
//  Wire3.setOpMode(I2C_OP_MODE_ISR);
  
  //Make sure runnning at 400 kHz
  Wire.setRate(I2C_RATE_400);
//  Wire1.setRate(I2C_RATE_400);
//  Wire2.setRate(I2C_RATE_400);
//  Wire3.setRate(I2C_RATE_400);
}
//END SETUP ****************************************************************

void loop() {
	device.read16NodeLine(buffer, Select_ZYX);
  //device.read64Nodes(buffer, Select_ZYX);
  
      //Print reading
      //Define the header of binary packets sent
        stream_packet_header[0] = 0x0A;
        stream_packet_header[1] = 0x0B;
        stream_packet_header[2] = 0x0C;
		//Serial.write(stream_packet_header,3);
		//Serial.write(buffer,NODE_64);

    for(int i = 0; i < NODE_64; i++)
    {
      Serial.print(buffer[i],HEX);
      Serial.print(" ");
    }
    Serial.print("\n");
		delay(1000);
}
//END LOOP *****************************************************************

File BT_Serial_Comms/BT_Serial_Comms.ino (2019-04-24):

#include "sdios.h"
String command = "";

#define BTSerial Serial1 //This serial port is linked to the BT transmitter
int BTSerial_baudrate = 115200;
int serial_baudrate = 115200;

void setup() 
{
   // Open serial communications and wait for port to open:
   Serial.begin(9600);
   Serial.println("Type AT commands!");
   // JY-MCU v1.03 defaults to 9600.
   BTSerial.begin(115200);
}

void loop()
{
   // Read device output if available.
   if (BTSerial.available()) {
     while(BTSerial.available()) { // While there is more to be read, keep reading.
       command += (char)BTSerial.read();
     }
     Serial.println(command);
     command = ""; // No repeats
   }
  
   // Read user input if available.
   if (Serial.available()){
       delay(10); // The DELAY!
       BTSerial.write(Serial.read());
   }
}// END loop()

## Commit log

2018-09-25 MagBoard 16 Node Arduino Code
    Operates on Teensy 3.6 platform
2018-09-25 MLX90393-Library for low-level communication with the MLX90393 Hall-Effect sensing chip
    First functional version. Not pretty but it works.
2018-09-30 Reconfigured structure of repository to include libraries and support docs
    Updated the repository so that it can track libraries, multiple arduino projects (linked to each MagSense application) and documentation.
    Should be compatible with Arduino Build environment, used the following references:
    https://arduino.stackexchange.com/questions/348/how-to-organize-my-arduino-projects-structure-for-easy-source-control
    https://gitlab.com/mikealger/ExampleArduinoProjectStructure/tree/master/ExampleSketchBook
2018-10-01 Added documentation on electronics files to 16 and 64 node systems
    [FootPlate_v1.brd, FootPlate_v1.sch]
2018-10-05 Draft implementation of asynchronous i2c calls
2018-10-12 Asynchronous code and removed some copy-paste
    Untested currently, stuff still needs adding to header files. Essentially have replaced blocking i2c with sendRequest. Use bytes.available to see when stuff is good to go in the isReadyFunction then go ahead and grab data. Have replaced some of the nasty copy-paste mux code with for loops and switch case. still lots of room for improvement.
2018-10-18 MagLib: Refactored reading to allow asynchronous reads
    Now each mux is set, followed by a function check to return the correct
    device object pointer; this is rather than using device1, device2...
    Eventually these should actually be moved into an array of objects.
    After finding the device, we can then go ahead and do an asynchrnous
    request for bytes for each wire1,wire2... This is done with the i2c
    sweep variable.
    At this point we're just sitting and waiting for all the devices to be
    ready, so we just wait for each to have wire.finish() and for bytes to
    be avaiable.
    Now one by one, go ahead and grab the data as before.
2018-10-18 MLX asynchronous support
    I2C_NOSTOP must be called at various points to keep the bus alive
2018-10-18 benchmark mode and i2c asynch setup
2018-10-18 Moved MLX devices into an object array
    Confusingly in the code there were two device objects. The top level one
    was for the board, eg device.read64nodes. There were also private device
    nodes device1,device2,... which reffered to MLX devices. They were
    really _virtual_ anyway because all they did different was contain an
    address and when the mux was changed it actually reffered to a different
    node all together.
    I have replaced the device objects with an array instead to make loop
    addressing easier. Also, have changed name to reflect that they actually
    just refer to addresses not actual nodes.
2018-10-18 Copyright, which wire, remove magic numbers
    Added copyright notice, same as Pete has used so far (MIT) since code is
    becoming mature and is publically available.
    Now have replaced a lot of the switch-case with a function that returns
    the correct wire object. This allows indexing for neatness.
    Have replaced some of the 'magic numbers' with constants defined in the
    header.
2018-10-19 Cleaned directory tree and removed version numbers
    Git can handle version numbering and so version numbers should not be
    included in file names
    [FootPlate_v1.brd, FootPlate_v1.sch]
2018-12-21 chris finished
    PCBs and code changes as of DEC2018
    Super fast i2c and coil designs as sent off to FS
    [Internal Layer 1.DXF, Internal Layer 1_FF.DXF, Internal Layer 1_FS.DXF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]
2019-01-29 File tidy + sort
    Started spring clean of files - no code change
    [FootPlate_v1.brd, FootPlate_v1.sch, Internal Layer 1.DXF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]
2019-02-04 Update HAILO files to current versions
    [FootPlate_v1.brd, FootPlate_v1.sch, HAILO_Splint_lores.stl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]
2019-02-10 Initial commit of Magboard UI Code
    Initial workings of UI codebase for Magboard
    Includes LabVIEW Client and Arduino Code
    Designed to provide command driven interface
    Still WIP!
2019-02-12 Update to MagBoard UI - Basic functionality working
    Now the system has a working LabVIEW client and Arduino master
    - system connection
    - system check
    - streaming over serial (memory leaks....)
    [MagBoard_n64_UI.ino]
2019-02-16 Implemented Bluetooth over Serial
    Basic functionality in place - works through standard Serial port on LabVIEW client
    Arduino code needs tidying with communications functions placed in MagLib library (not main code).
2019-02-28 Added initial version of strain map into LabVIEW Client
    Strain map shows XYZ displacements of nodes
    Work required to tidy and calibrate sensor response
2019-03-25 Initial Commits to SD logging
    [Logging_Calculations.xlsx]
2019-04-15 SD Logging example added to repo
    Test SdFAT based datalogging to SD card on the inbuilt Teensy 3.6 card holder.
    works nicely.
2019-04-24 SD card logging and upload complete
    Added full support for logging to SD card
    Arduino code supports logging, upload and testing filesystem
    LabVIEW Client supports all above - with some bug fixes
    [BT_Serial_Comms.ino, MagBoard_n64_UI.ino, SD_Logging_Test.ino]
2019-05-13 Started addition of improved MLX chip configuration
    Adding offsets to Z axis and configuring gains etc
2019-05-31 Initial NN sensor calibration added
    Integrated NN calibration functions into UI and FileReader
    Calibration files added to project.
    LabVIEW Version currently v2016.
    NB - Future commits will use LabVIEW v2018
2019-10-15 Added error checking for 128 node board tests
2019-10-17 Added 128 board node layout details
2019-10-29 Improved I2C scan stability and menu interface with Serial
2019-10-31 Improved robustness and basic led interface
2019-11-04 Adjusted MLX90393 sensor Gain/Resolution config
2019-11-07 Fixed bugs for swapping between 64/128 node boards
2019-11-27 Added updated LabVIEW code for 128 Node Board Client
    [MagBoard128_SensorLocations.xlsx, MagBoard128_SensorLookup_Indices.csv]
2019-11-29 Improved data packet organisation across multiple devices
2019-12-11 Finalised Footplate software for CAH Clinical Trials
    [MagBoard128_SensorLocations.xlsx, MagBoard128_SensorLookup_Indices.csv, SensorLocations.csv]
2019-12-16 Fixed minor bugs, verified code base for both 64 and 128 node magboards
    [MagBoard128_SensorLocations.xlsx, MagBoard128_SensorLookup_Indices.csv, SensorLocations.csv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]
2020-01-07 Improved 3D graph and user interface
    [MagBoard128_SensorLocations.xlsx, MagBoard128_SensorLookup_Indices.csv, SensorLocations.csv]
2020-01-08 Added new NN calibration file and removed minor labview bugs
2020-01-13 Fixed labview file reading bug and added BLE GATT profile
    [MagBoard128_SensorLocations.xlsx, SensorLocations.csv]
2020-01-24 Added BracePLUS labview client
    [SensorLocations.csv]
2020-02-18 Final webcam + UI improvements
    [ESCAPES_Max_01_B__01311125.csv, ESCAPES_Max_02_B__01311127.csv, ESCAPES_Max_03_B__01311127.csv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]
2020-02-21 ESCAPES Trials Code
    [STR_TEST_2_05_A__DA74770D.csv]
2020-03-27 Fixed MagLib bugs, tested programs for each platform and separated into designated System Program folders
    [Trial Notes.xlsx]
